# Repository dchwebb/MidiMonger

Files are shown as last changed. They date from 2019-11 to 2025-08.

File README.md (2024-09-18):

<p align="center"><a href="https://www.pcbway.com"> PCBWay</a></p>

# MidiMonger v2
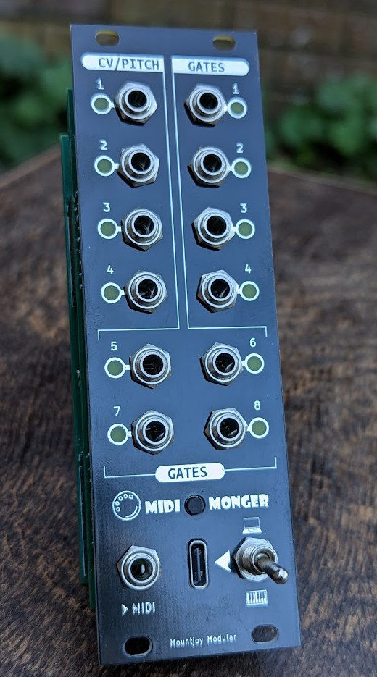
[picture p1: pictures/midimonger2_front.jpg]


MidiMonger is a Eurorack MIDI interface supporting USB and serial MIDI. 

MIDI Monger is a configurable MIDI interface for controlling Eurorack modules from either USB MIDI or Serial MIDI (or both simultaneously). MidiMonger 2 adds support for USB host functionality allowing the use of USB MIDI controllers (and experimentally USB HID mice) to control Eurorack modules.

MIDI Monger has 12 outputs of which 8 are gate outputs and 4 are control voltage outputs. The first eight outputs are configured by default as channel pairs. When assigned a MIDI channel they will act as a monophonic gate/cv driven from a single MIDI channel or in polyphonic mode supporting up to 4 note polyphony.

When not used in a pair a gate output can send a gate for any MIDI note from a channel, for a specific note number on a channel (eg for use as drum triggers) or a clock. The Control Voltage outputs can be configured to send controller data, pitch bend or aftertouch.

Configuration is carried out from a [web interface](https://htmlpreview.github.io/?https://github.com/dchwebb/MidiMonger/blob/master/WebEditor/index.html) using the Chrome browser or via a Virtual COM Port:

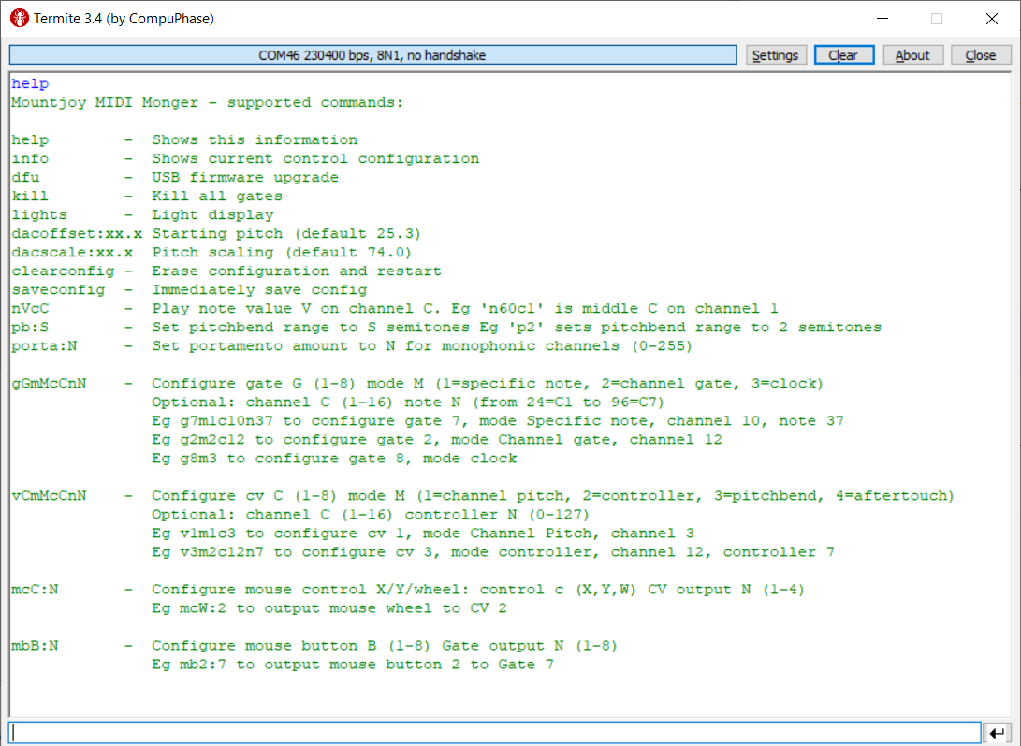
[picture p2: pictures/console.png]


# USB
MidiMonger can act as either a USB device (typically for connection to a computer) or a USB Host (allowing USB Midi controllers to be connected). The mode is selected using a switch on the front panel and is connected with a USB-C socket.

In USB device mode USB MIDI data is merged with MIDI Serial data and sent to the CV and gate outputs as configured. In host mode USB devices can be connected directly to the module. This is typically used for MIDI keyboards and controllers that output via USB, but experimental support is also provided for USB HID devices - mouse support is currently implemented, but joysticks etc could be implemented in the future.

When connecting a USB mouse by default the left/right up/down and mouse wheel are output on CV 1, 2 and 3 and the buttons are output to the gates. This can be configured using the serial console.

In host mode the device will output 5v to power connected devices, but it is not recommended use with power hungry devices as the 5v rail is supplied via a linear regulator which has limited power output and also is used to supply a reference voltage to the DAC.

# Technical
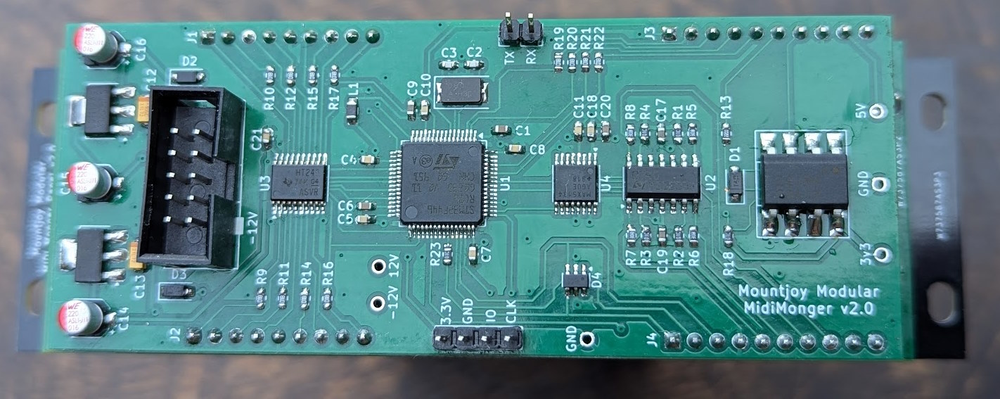
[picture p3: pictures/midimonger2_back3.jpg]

MIDI Monger is controlled by an ARM STM32F446 Microcontroller. The MCU manages USB (device and host modes) and serial MIDI. Control voltages are output from a Maxim MAX5134 16 bit DAC controlled by SPI.

Gate outputs are converted to Eurorack standard of 5V using a SN74HCT244 Octal buffer as a level shifter. MIDI Serial signals are buffered through a 6N137 Optocoupler.

A UART connection is also provided to the module allowing access to the serial console when operating in USB host mode.

Serial MIDI is supplied via a 1/8" TRS jack using the MIDI standard wiring.

Digital power is supplied from a 3.3v linear regulator. An additional 5v regulator is used to supply a reference voltage to the DAC, as power for the octal buffer and also to provide power to USB devices when operating in USB Host mode.

The module is constructed using three PCBs: a component board, a control board and a panel. Schematics and PCB layout created in KiCad v8 and available in [Hardware folder](https://github.com/dchwebb/MidiMonger/tree/master/Hardware_v2).

[Components schematic](Hardware_v2/MidiMonger_Components.pdf)

[Controls schematic](Hardware_v2/MidiMonger_Controls.pdf)

# Errata (v2 hardware)
- The 3.3v linear regulator runs quite warm - some passive PCB cooling would be a good idea or possibly the use of a switched mode power supply (no analog voltages are supplied from this rail).
- A separate switched mode 5V rail would allow the connection of more power hungry USB devices without risking noise or sagging on the analog 5V reference.
- The USB device/host icons on the mode switch front panel should be swapped.
- To allow PWM brightmess control over the CV LEDs, CV1_LED and CV2_LED should be switched to pins lined to TIM4 (CV3_LED and CV4_LED connected to TIM4_CH2 and CH3)

# Version 1 Hardware
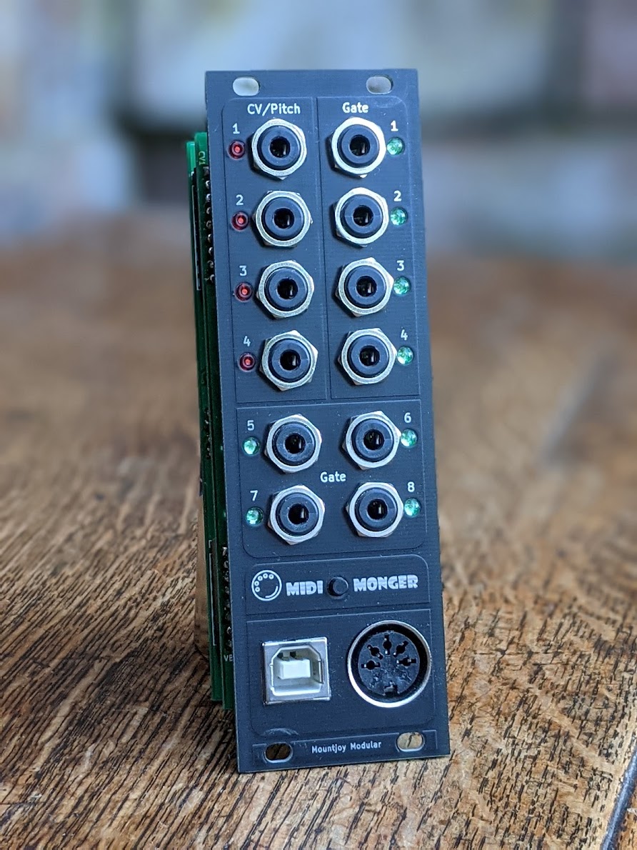
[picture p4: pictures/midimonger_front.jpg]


The original version of the module works with the latest firmware using the build in [V1 Hardware folder](https://github.com/dchwebb/MidiMonger/tree/master/MidiMonger2/v1Hardware). The main differences are that the v1 hardware does not support USB host mode, uses a full size MIDI DIN connector and a USB B socket.

Sponsorship
-----------

[PCBWay](https://www.pcbway.com/) were kind enough to sponsor the v2 module, manufacturing and supplying the three PCBs used for the component and control boards as well as the front panel. The quality of each PCB was excellent and the fine details were crisp and precise. Hand-soldering the fine-pitch components on the prototypes was extremely easy thanks to the high quality accuracy of the solder mask.

Many thanks to PCBWay for their generosity in sponsoring this project and their services come highly recommended.

<p align="center"><a href="https://www.pcbway.com"> PCBWay</a></p>

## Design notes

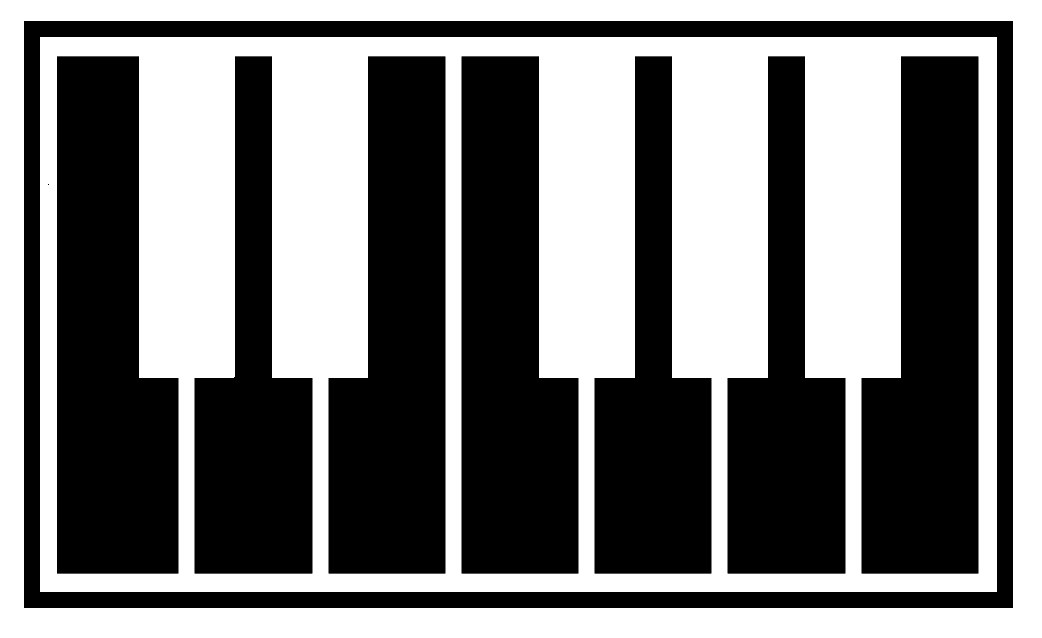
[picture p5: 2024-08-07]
Hardware_v2/Graphics/piano.jpg

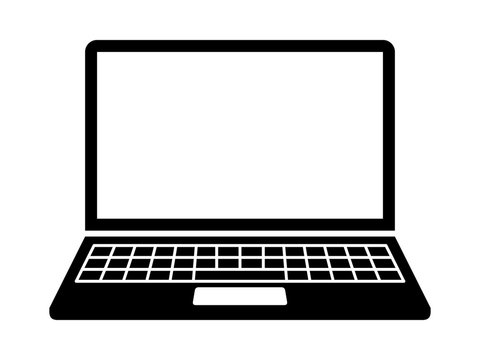
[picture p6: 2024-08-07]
Hardware_v2/Graphics/computer.jpg

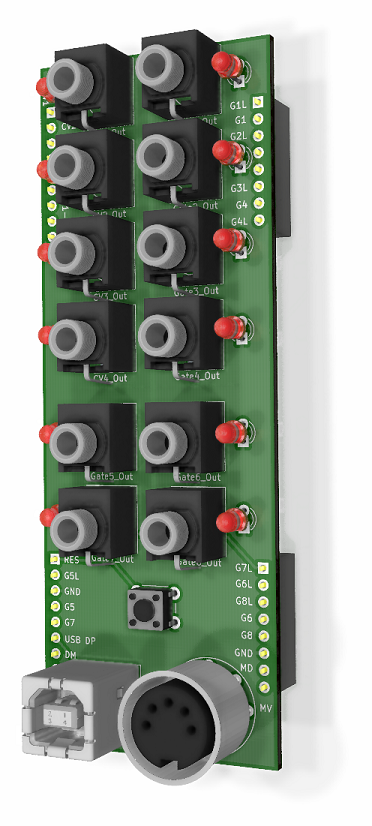
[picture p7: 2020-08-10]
pictures/controls.png

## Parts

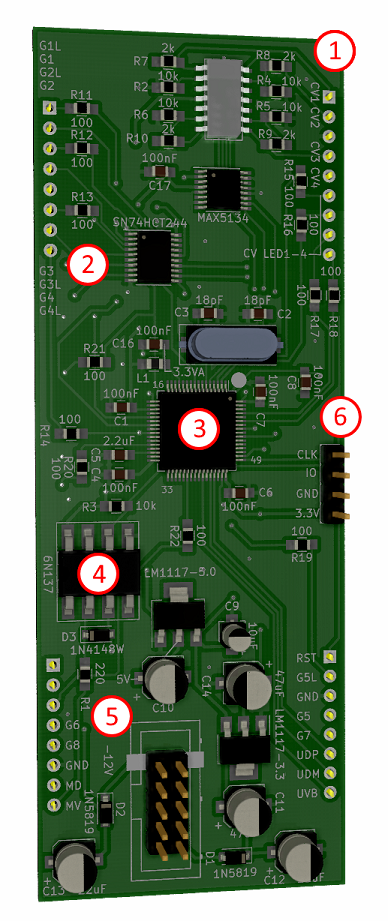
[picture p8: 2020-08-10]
pictures/components.png

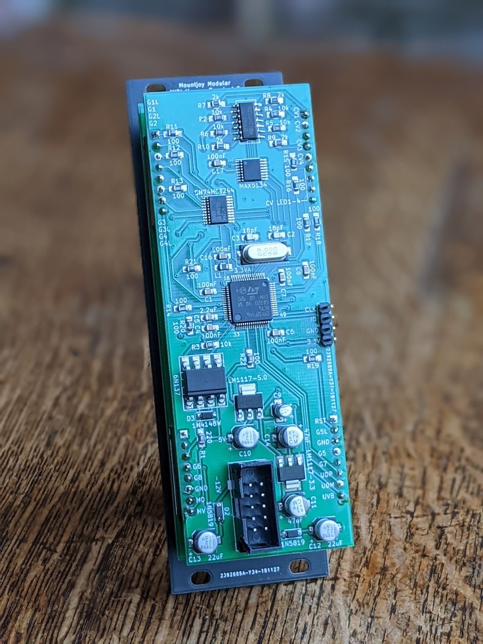
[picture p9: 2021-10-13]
pictures/midimonger_components.jpg

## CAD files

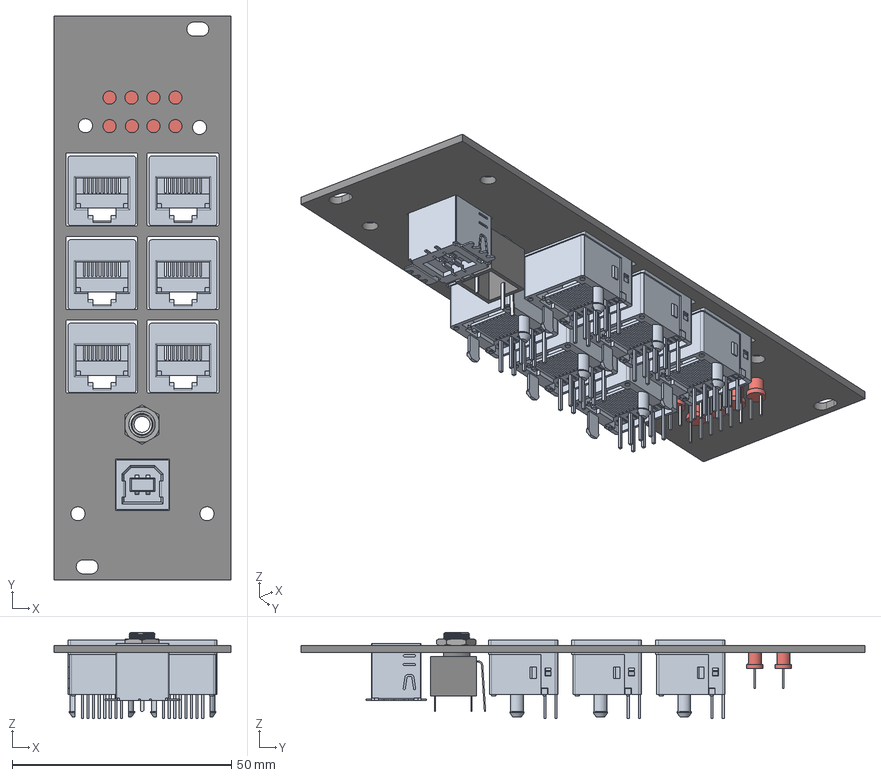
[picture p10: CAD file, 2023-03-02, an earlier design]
Hardware_v1/Graphics/QMidiMonger_panel.step
40.3 x 128.5 x 19.7 mm
QMidiMonger_panel PCB

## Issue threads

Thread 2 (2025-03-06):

enumeration

bgapackage, 2025-03-06:
this does not enumerate in device mode on macosx, not sure why

dchwebb, 2025-03-07:
I haven't actually tested it on macosx as I only have access to a Windows PC here. However it _should_ work.

The module has two modes - it can operate as a device (for connecting it to a computer) or as a host (for connecting to a midi keyboard or mouse). This is controlled by the switch at the bottom right. I think the graphic is unclear and should really be reversed, but up is host mode and down is device mode.

So make sure the switch is in the down position and connect to a computer.

If that doesn't work then it would be worth testing the usb connection by using it in host mode. To do this move the switch to the up position and connect a usb mouse. If you move the mouse or click the buttons the leds should show some activity.

If neither of these work I would guess there is a problem with the soldering, probably around the usb socket.

dchwebb, 2025-03-07:
I'm not sure about the enumeration issue as I don't have a Mac to test on. Any chance you can try it on a Windows machine to see if that works?

Regarding the gate staying high - I have implemented a provisional fix which can be found here:

https://github.com/dchwebb/MidiMonger/tree/master/MidiMonger2/v2Hardware

bgapackage, 2025-03-07:
thanks, ill give that a try.
if it enumerates on windows but not on osx, what do you think it could be? the descriptor?

dchwebb, 2025-03-07:
I really don't know. I can try and test it on Linux which I think has a similar USB engine to MacOS.

Obviously if you could find any troubleshooting tool to provide more info that would be really useful.

dchwebb, 2025-03-08:
I've just tested on Linux and I am seeing descriptor errors and it fails to enumerate. By comparison I have looked at another module of mine which enumerates fine.

This gives me some confidence that I have a replicable issue that I can solve that hopefully will help on a Mac.

bgapackage, 2025-03-08:
amazing, im also trying to debug. keep me posted.

dchwebb, 2025-03-08:
I've done a bit more testing between the module that works and MidiMonger. MidiMonger still fails when I make the descriptors exactly the same as the working module. This implies that the issue is in the way the firmware handles enumeration, rather than a fault in the descriptors themselves.

I'm setting up a debug environment now and hopefully can get to the bottom of it.

dchwebb, 2025-03-09:
I've found and corrected the issue that was preventing the device from being recognised under Linux - it is possible this will fix the issue you have seen on the Mac:

https://github.com/dchwebb/MidiMonger/tree/master/MidiMonger2/v2Hardware

I have noticed one other problem under Linux which is that the serial console is not appearing correctly, though seems to enumerate. If this does now enumerate on your Mac would be you be able to see if you can access the serial terminal?

bgapackage, 2025-03-09:
yep that enumerates and can access serial too. much appreciated

bgapackage, 2025-03-09:
thank you

Closed 2025-03-09.

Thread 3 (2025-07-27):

MidiMonger Roli Seaboard Midihost

tsanderakis, 2025-07-27:
Did this morning some tests to get it running without success.
Direct chain Seaboard going into MidiMonger I can see all CV LEDs going on and off after assigning them from terminal. But there are no cv outs going fe. to Kishoof and s VCF.
When I make the chain Seaboard ->Laptop->MidiOX->Standard Midi Interface->Oscar!->MidiMonger and then to Kishoof / VCF everything is working fine as it should be. Fun to see Midi Data on Oscar. All CV LEDs go on and off and you can hear also the changes  of pitch, on Kishoof, filter or whatever is connected.
Seaboard is connected with an external 12V PSU so I think it will do no harm to the USB connectionr in MidiMonger. No magic smoke and the USB port still working.
Also tried to connect from the web interface and Google Chrome without success. I allowed Chrome to do this but two interfaces not working.
One is a Steinberg and the other a cheap chinese.

tsanderakis, 2025-07-27:
Sorry, no scope here in the moment.
But in this chain including Laptop as Midihost also Gate 1 is working and I use it for opening the VCA in Kishoof.
But as far as I try it in direct connection with Seaboard and MidiMonger Gate 1 no LED.
CV 2, 3, 4, seem to work, as when I connect CV2, CV3, CV4 to the pitch in of Kishoof I can hear the pitch a little bit changing. Ok, this depends on the Midicontrol No.s
In the Laptop chain I can also send cv to a VCF behind Kishoof, so everything fine.
In the direct chain, Seaboard -> MidiMonger CV1 led goes on, but no CV or change and no gate outat No. 1.

And nothing changed with terminal in the setup. Just  changing cables.

tsanderakis, 2025-07-27:
Looks like the translation from Midi In of MidiMonger looks ok, but from Host / USB input not.

dchwebb, 2025-07-27:
Have you set the Device/Host switch to the correct position?

tsanderakis, 2025-07-27:
to the top.
To the bottom nothing to see. No LEDs

dchwebb, 2025-07-27:
Switch up is correct.

I don't suppose you have a UART to serial device? There is a UART console in the module that is useful for troubleshooting USB host MIDI as you don't have access to the normal console in this mode. I use the FTDI friend: https://www.adafruit.com/product/284?srsltid=AfmBOoqUQp6svEJ_5urM25LUVzh_FfFFfu_P-VOsosdgvDhkcROMc2NS

In any case I am assuming that the configuration is not correct. If you go back to device mode and connect to your computer can you use the 'info' command in the console to view your existing configuration?

You will need to know what channel the Seaboard is transmitting on and match your config to that channel. By default the first pair of gate and cvs are connected to MIDI channel 1, the second to channel 2 etc.

tsanderakis, 2025-07-27:
dfu         -  USB firmware upgrade
kill        -  Kill all gates
lights      -  Light display
dacoffset:xx.x Starting pitch (default 25.3)
dacscale:xx.x  Pitch scaling (default 74.0)
clearconfig -  Erase configuration and restart
saveconfig  -  Immediately save config
nVcC        -  Play note value V on channel C. Eg 'n60c1' is middle C on channel 1
pb:S        -  Set pitchbend range to S semitones Eg 'p2' sets pitchbend range to 2 semitones
porta:N     -  Set portamento amount to N for monophonic channels (0-255)

gGmMcCnN    -  Configure gate G (1-8) mode M (1=specific note, 2=channel gate, 3=clock)
               Optional: channel C (1-16) note N (from 24=C1 to 96=C7)
               Eg g7m1c10n37 to configure gate 7, mode Specific note, channel 10, note 37
               Eg g2m2c12 to configure gate 2, mode Channel gate, channel 12
               Eg g8m3 to configure gate 8, mode clock

vCmMcCnN    -  Configure cv C (1-8) mode M (1=channel pitch, 2=controller, 3=pitchbend, 4=aftertouch)
               Optional: channel C (1-16) controller N (0-127)
               Eg v1m1c3 to configure cv 1, mode Channel Pitch, channel 3
               Eg v3m2c12n7 to configure cv 3, mode controller, channel 12, controller 7

mcC:N       -  Configure mouse control X/Y/wheel: control c (X,Y,W) CV output N (1-4)
               Eg mcW:2 to output mouse wheel to CV 2

mbB:N       -  Configure mouse button B (1-8) Gate output N (1-8)
               Eg mb2:7 to output mouse button 2 to Gate 7
info
Configuration:
DAC offset: 25.299999
DAC scale: 74.000000
Pitchbend range: 12.000000 semitones
Portamento amount: 0
Config sector: 5; address: 0x8020360

Gate 1: Channel Gate. Channel: 1 [Mouse Button: 5]
Gate 2: Channel Gate. Channel: 2 [Mouse Button: 6]
Gate 3: Channel Gate. Channel: 3 [Mouse Button: 7]
Gate 4: Channel Gate. Channel: 4 [Mouse Button: 8]
Gate 5: Specific Note. Channel: 10 Note: 36  [Mouse Button: 1]
Gate 6: Specific Note. Channel: 10 Note: 38  [Mouse Button: 2]
Gate 7: Specific Note. Channel: 10 Note: 42  [Mouse Button: 3]
Gate 8: Specific Note. Channel: 10 Note: 46  [Mouse Button: 4]
CV 1: Channel Pitch. Channel: 1 [Mouse: X]
CV 2: Aftertouch. Channel: 1 [Mouse: Y]
CV 3: Controller: 74. Channel: 1 [Mouse: Wheel]
CV 4: Controller: 113. Channel: 1 [Mouse: ]

Only changed CV 2,3 and 4
Rest is default.

dchwebb, 2025-07-27:
That looks ok assuming Seaboard is outputting on channel 1. Can you examine Seaboard's Midi data to check?

tsanderakis, 2025-07-27:
Everything is channel No. 1, because its in Mono Mode. Normally MPE goes polyphonic over severa chanels.
I can try to check with MidiOX whats it sending.

tsanderakis, 2025-07-27:
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
Sorry, think there is no plain text export in Midi OX.
This is a screen shot

tsanderakis, 2025-07-27:
113 / 114 are not coming from the keyboard. This is an extra 5x5cm pad x y.

dchwebb, 2025-07-27:
I'm out of ideas at the moment. I'll see if I can think of any thing further.

tsanderakis, 2025-07-27:
So lets finish for today. Tomorrow is shopping and later I have to do my taxes for 2024 until end of this month. Nothing is running away here so we have time.

tsanderakis, 2025-08-20:
first test
one easy keyboard my old Midiplus 61.
v1m1c1
Configured: v1m1c1
saveconfig
Config Saved (144 bytes at 0x080203f0)
g1m1c1
saveconfig
Config Saved (144 bytes at 0x08020480)

Just activating CV1 and Gate1

CV1 looks good and Kishoof is playing.
Gate1 not.
LED stays on and does not go off and also Gate of Kishoof stays open.

info
Configuration:
DAC offset: 25.299999
DAC scale: 74.000000
Pitchbend range: 12.000000 semitones
Portamento amount: 0
Config sector: 5; address: 0x8020480

Gate 1: Channel Gate. Channel: 1 [Mouse Button: 5]
Gate 2: Channel Gate. Channel: 2 [Mouse Button: 6]
Gate 3: Channel Gate. Channel: 3 [Mouse Button: 7]
Gate 4: Channel Gate. Channel: 4 [Mouse Button: 8]
Gate 5: Specific Note. Channel: 10 Note: 36  [Mouse Button: 1]
Gate 6: Specific Note. Channel: 10 Note: 38  [Mouse Button: 2]
Gate 7: Specific Note. Channel: 10 Note: 42  [Mouse Button: 3]
Gate 8: Specific Note. Channel: 10 Note: 46  [Mouse Button: 4]
CV 1: Channel Pitch. Channel: 1 [Mouse: X]
CV 2: Aftertouch. Channel: 1 [Mouse: Y]
CV 3: Controller: 74. Channel: 1 [Mouse: Wheel]
CV 4: Controller: 113. Channel: 1 [Mouse: ]

Have I done something wrong when configuring?
Just the simplest way pitch on CV1 and Gate on Gate one

tsanderakis, 2025-08-20:
Here it is not working. The normal Midi In works fine but on Midi Host allways the gate stays on. I tested it also with Midi Channel 2 with same result. Gate stays on and this is the problem. I have now two keyboards connected. Old Midiplus 61 and my Arturia Keystep Pro. Both sending on Channel1 and back fom testing Midi Channel 2 to Channel 1. On both Keyboards I can play, works as a Midi Merger, but with Midihost Gate stayes on and when playing the Arturia everything is fine. Even when Gate is on, one Note from the Arturia switches the Gate off.

tsanderakis, 2025-08-20:
The normal Midi In is fine. Just playing Arpeggio with 210BPM which was fast. Nothing hanging and working perfect with a speed nobody is realy using in practice. Normal Midi In is working for 100%.

dchwebb, 2025-08-20:
I might see if I can add some further debugging. By the way have you tried out this debugging mechanism yet?

> You can view the attempted connection log by connecting a device in host mode, then disconnecting. Without restarting the module, switch to device mode and attach to a computer. You can then use a serial console viewer to display the connection details using the command 'hostlog'.

If that works for you then we can get diagnostics of the MIDI host mode over a normal USB connection.

tsanderakis, 2025-08-20:
No, had just a little bit food and fighting now with missing Arturia Passwords that I can connect the Keystep Pro to its Software. MidiOX is not working for 100% now on my computer. Seaboard is found, but the two other keyboards not and this not a save testing ground, Maybe USB cable to long or something wrong with it?

tsanderakis, 2025-08-20:
hostlog

Starting ...
Switching to device mode
USB Device Connected
USB Device Reset Completed
Device Attached. Speed: FS
Enumeration: Got max packet size: 64
Enumeration: Get full device descriptor
 - PID: 0x35
 - VID: 0xccd
Enumeration: Address 1 assigned
Enumeration: Get configuration descriptor size
Enumeration: Got full configuration descriptor
Enumeration: Manufacturer N/A
Enumeration: Product PHECDA USB/MIDI Device
Enumeration: Serial Number N/A
Enumeration done. Device has 1 configuration(s)
Default configuration set
MIDI Class Init
Switching to Interface 1
Class    : 1h
SubClass : 3h
MIDI class started
MIDI Class Process: Init
MIDI Class DeInit
USB Device disconnected
Switching to device mode

dchwebb, 2025-08-22:
I've created a basic debug mechanism to capture raw MIDI events so I can 'replay' them at my end and hopefully see what's going wrong. The way it works is that the first 200 events are captured and can then be displayed in device mode. So it would be great if you could hook up a keyboard that is not working in host mode and play some notes.

Then disconnect, switch to device mode, and connect to a computer. From the serial command line you now have two commands 'eventlistraw' and 'eventlist'. The first dumps the raw MIDI events onto the screen and the second outputs them in a more formatted way. If you could send me the two versions over then I can analyse the data and replay in my module to see if I can fix the issue.

Thanks!
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
tsanderakis, 2025-08-22:
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
And this is what my Keystep Pro is sending to MidiOX. Think it is on Midi Channel1.
When I connect Keystep Pro to MidiMonger there is no reaction and it seems that when controlling with eventlistraw no data has flown and nothing is in the buffer.

tsanderakis, 2025-08-22:
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

Seaboard in Midi OX
Line3 is Note On

tsanderakis, 2025-08-22:
After experimenting with "active sensing" it seems now that USB output of my Midiplus 61 is dead. No more found by MidiOX and tried it on to different PCs. So I need a brake to look whats going on. Active sensing is not clock. Old Keyboards were doing this to look allways if the partner in the chain is responding. On Midiplus61 I see no chance to switch it off. Active sensing information is also on 5pin Midi Out of Midiplus 61 when connected to MidiOX. This is the only midi out working in the moment. USB is comletly dead. Maybe this active sensing is the problem. To much Data?

http://midi.teragonaudio.com/tech/midispec/sense.htm

tsanderakis, 2025-08-22:
Coming back to Seaboard and what I found last evening:
LED on MidiMonger was going on and off when a key was pressed on Seaboard, but when I switched Kishoof and my little speaker on I could hear just a drone and no change in pitch. Midi-hell???
The normal Midi Input of MidiMonger is for me and for now working 100% until now. Ok, have not checked all CV and Gate outs.
But CV1 and Gate1 perfect and as I told you just for testing with an arpeggio with 210bpm.

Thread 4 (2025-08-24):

Midiplus61 Problems

dchwebb, 2025-08-24:
@tsanderakis

I have updated the debugging mechanism to provide a bit of extra detail about potential problems and to filter out the active sensing and blank data events.

Also you only need to run the 'eventlist' command as this contains the raw data and some extra debugging stuff.

Would you mind trying out the new firmware with the Midiplus61 and supplying the resulting event log, please?

tsanderakis, 2025-08-24:
eventlistraw
0x0001b00b
0x0201b00b
0x52309009
0x00309009

Gate LED stays still on.

tsanderakis, 2025-08-24:
eventlist
CIN cable chn msg  db1 db2 Raw
 11     0   0 0x0b   1   0 0x0001b00b
 11     0   0 0x0b   1   2 0x0201b00b
  9     0   0 0x09  48  82 0x52309009
  9     0   0 0x09  48   0 0x00309009
Filtered events: 1964; Multi data events: 123; Split events: 0

tsanderakis, 2025-08-24:
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
Midi Implementation Chart Midiplus61

dchwebb, 2025-08-24:
Firmware updated. Would you mind trying it out for me, please?

tsanderakis, 2025-08-24:
looks nice

dchwebb, 2025-08-24:
Great. I'll close this issue and open a new one for the Arturia Keystep.

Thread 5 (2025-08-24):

Not working with Arturia Keystep

dchwebb, 2025-08-24:
@tsanderakis

Could you try connecting the Keystep and then running the _hostlog_ command in device mode - that will give me a starting point to see why not being recognised.

tsanderakis, 2025-08-24:
eventlistraw
Raw        CIN cable chn msg  db1 db2
Filtered events: 0; Multi data events: 0; Split events: 0

dchwebb, 2025-08-24:
NO - the _hostlog_ command

tsanderakis, 2025-08-24:
But I think we have no chance with this message No registered class for this device.
Think that these USB Keyboards need special drivers installed and then this is enless work.

I`m out and offline for the next 4h todo some sports.

dchwebb, 2025-08-24:
@tsanderakis
Sorry I realised I had not actually updated the firmware on Github, but that is now done.

I've also reworked the code to potentially get the host mode working with Misc class devices (ie hopefully the Keystep and Venom). Could you give it a go if you have a minute, and send me the descriptor debug output in either case?

tsanderakis, 2025-08-24:
Starting ...
USB Device Connected
USB Device Reset Completed
Device Attached. Speed: FS
Enumeration: Got max packet size: 64
Enumeration: Get full device descriptor
 - PID: 0x218
 - VID: 0x1c75
Enumeration: Address 1 assigned
Enumeration: Get configuration descriptor size
Enumeration: Got full configuration descriptor
Enumeration: Manufacturer Arturia
Enumeration: Product KeyStep Pro
Enumeration: Serial Number 000000000001
Enumeration done. Device has 1 configuration(s)
Default configuration set
No registered class for this device 0xfe
USB Device disconnected
Switching to device mode

tsanderakis, 2025-08-25:
After digging deep into all my cabelboxes and other stuff I found my external Midi Host back this morning.
Miditech USB Midi Host
https://miditech.de/en/portfolio/usb-midi-host/

Keystep to Miditech USB Midi Host to MidiMonger
And it`s working!
And this is nothing where you have to install drivers. Just Hardware and found. There must be a way that MidiMonger will find these Keyboards.

But,
test No. 2 this morning, changed over to the old Venom, it`s not working. So there must be something else.
And at the end I just ordered for r&d a cheap USB Midihost for 25€ and then let`s look and see what this little box is doing.
Arriving ~thursday.

tsanderakis, 2025-08-25:
hostlog
USB Device Connected
USB Device Reset Completed
Device Attached. Speed: FS
Enumeration: Got max packet size: 64
Enumeration: Get full device descriptor
 - PID: 0x218
 - VID: 0x1c75
Enumeration: Address 1 assigned
Enumeration: Get configuration descriptor size
Enumeration: Got full configuration descriptor
Enumeration: Manufacturer Arturia
Enumeration: Product KeyStep Pro
Enumeration: Serial Number 000000000001
Enumeration done. Device has 1 configuration(s)
Default configuration set
No registered class for this device 0xfe
USB Device disconnected
USB Device Connected
USB Device disconnected
Switching to device mode

dchwebb, 2025-08-26:
Thanks - I've had another go at fixing. Could you try again at some point, please?

tsanderakis, 2025-08-26:
Looks good now and working. Have my CV and my Gate and Kishoof is playing.

hostlog

Starting ...
USB Device Connected
USB Device Reset Completed
Device Attached. Speed: FS
Enumeration: Got max packet size: 64
Enumeration: Get full device descriptor
 - PID: 0x218
 - VID: 0x1c75
Enumeration: Address 1 assigned
Enumeration: Get configuration descriptor size
Enumeration: Got full configuration descriptor
Enumeration: Manufacturer Arturia
Enumeration: Product KeyStep Pro
Enumeration: Serial Number 000000000001
Enumeration done. Device has 1 configuration(s)
Default configuration set
MIDI Class Init
Switching to Interface 2
Class    : 1h
SubClass : 3h
MIDI class started
MIDI Class Process: Init
MIDI Class DeInit
USB Device disconnected
Switching to device mode

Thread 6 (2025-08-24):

Not working  with Venom

tsanderakis, 2025-08-24:
hostlog

USB Device Connected
USB Device Reset Completed
Device Attached. Speed: FS
Enumeration: Got max packet size: 64
Enumeration: Get full device descriptor
 - PID: 0x2084
 - VID: 0x763
Enumeration: Address 1 assigned
Enumeration: Get configuration descriptor size
Enumeration: Got full configuration descriptor
Enumeration: Manufacturer M-Audio
Enumeration: Product Venom
Enumeration: Serial Number N/A
Enumeration done. Device has 1 configuration(s)
Default configuration set
MIDI Class Init
Error: Cannot Select This Interface
Cannot Find the interface for MIDI class
Device does not support MIDI class
MIDI Class DeInit
USB Device disconnected
Switching to device mode

This is my no.4 and last keyboard with USB und it seems that it is the same problem like Keystep Pro.

Device does not support MIDI class

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

dchwebb, 2025-08-26:
It looks like the problem with the Venom is possibly because the USB descriptor is larger than the current maximum size allowed in MidiMonger. I've increased the maximum size so if you could try again that would be great.

tsanderakis, 2025-08-26:
hostlog

Starting ...
USB Device Connected
USB Device Reset Completed
Device Attached. Speed: FS
Enumeration: Got max packet size: 64
Enumeration: Get full device descriptor
 - PID: 0x2084
 - VID: 0x763
Enumeration: Address 1 assigned
Enumeration: Got configuration descriptor size
Enumeration: Got full configuration descriptor
Enumeration: Manufacturer M-Audio
Enumeration: Product Venom
Enumeration: Serial Number N/A
Enumeration done. Device has 1 configuration(s)
Default configuration set
MIDI Class Init
Error: Cannot Select This Interface
Cannot Find the interface for MIDI class
No registered class for this device 0x01
USB Device disconnected
Switching to device mode

dchwebb, 2025-08-26:
There's something a bit funny about that descriptor - it could be that I'm not parsing it correctly or it could have an odd format.

If you are happy to keep on going with the debugging I'll write some additional tools to help find out where this is failing.

dchwebb, 2025-08-26:
OK - if you update to the latest firmware there is a new command 'rawconfigdesc' which will output the raw configuration descriptor data so I can see why the parsing is not working correctly.

tsanderakis, 2025-08-26:
So just in between before going on, there is maybe one more problem with the firmware. I was feeding MidiMonger from Keystep Pro with a sequence ~120BPM, having a beer, enjoying this crazy music, and what happend after ~7,8,10min??? MidiMonger is frozen. Short reset and everything is fine again. After the same time- again frozen. So I can reproduce this issue.
Think I will play a little bit more tomorrow to find out if there are more problems.

tsanderakis, 2025-08-26:
rawconfigdesc
Raw configuration descriptor data
0x09 0x02 0x48 0x01 0x05 0x01 0x04 0xc0
0000 0x09 0x04 0000 0000 0000 0x01 0x01
0000 0x03 0x0b 0x24 0x01 0000 0x01 0x49
0000 0x03 0x01 0x02 0x03 0x0c 0x24 0x02
0x01 0x01 0x01 0x02 0x02 0x03 0000 0000
0000 0x09 0x24 0x03 0x02 0x01 0x03 0x01
0x06 0000 0x0c 0x24 0x02 0x03 0x01 0x02
0x04 0x02 0x03 0000 0000 0000 0x09 0x24
0x03 0x04 0x01 0x01 0x03 0x05 0000 0x0a
0x24 0x06 0x05 0x03 0x01 0x01 0000 0000
0000 0x0a 0x24 0x06 0x06 0x01 0x01 0x01
0x02 0x02 0000 0x09 0x04 0x01 0000 0000
0x01 0x02 0000 0000 0x09 0x04 0x01 0x01
0x02 0x01 0x02 0000 0000 0x07 0x24 0x01
0x01 0x02 0x01 0000 0x0b 0x24 0x02 0x01
0x02 0x03 0x18 0x01 0x44 0xac 0000 0x09
0x05 0x02 0x05 0x3e 0x01 0x01 0000 0x86
0x07 0x25 0x01 0x01 0000 0000 0000 0x09
0x05 0x86 0x01 0x10 0000 0x01 0x06 0000
0x09 0x04 0x02 0000 0000 0x01 0x02 0000
0000 0x09 0x04 0x02 0x01 0x01 0x01 0x02
0000 0000 0x07 0x24 0x01 0x04 0x01 0x01
0000 0x0b 0x24 0x02 0x01 0x02 0x03 0x18
0x01 0x44 0xac 0000 0x09 0x05 0x84 0x05
0x3e 0x01 0x01 0000 0000 0x07 0x25 0x01
0x01 0000 0000 0000 0x09 0x04 0x03 0000
0x02 0x01 0x03 0000 0x03 0x07 0x24 0x01
0000 0x01 0x61 0000 0x06 0x24 0x02 0x01
0x01 0x05 0x06 0x24 0x02 0x01 0x02 0x06
0x06 0x24 0x02 0x02 0x03 0x07 0x06 0x24
0x02 0x02 0x04 0x08 0x09 0x24 0x03 0x01
0x05 0x01 0x03 0x01 0x07 0x09 0x24 0x03
0x01 0x06 0x01 0x04 0x02 0x08 0x09 0x24
0x03 0x02 0x07 0x01 0x01 0x01 0x05 0x09
0x24 0x03 0x02 0x08 0x01 0x02 0x02 0x06
0x09 0x05 0x0d 0x02 0x40 0000 0000 0000
0000 0x06 0x25 0x01 0x02 0x01 0x02 0x09
0x05 0x8e 0x02 0x40 0000 0000 0000 0000
0x06 0x25 0x01 0x02 0x05 0x06 0x09 0x04
0x04 0000 0000 0xfe 0x01 0x01 0x09 0x09
0x21 0x01 0xd0 0x07 0x0c 0x20 0x01 0x01
0000 0000 0000 0000 0000 0000 0000 0000
0000 0000 0000 0000 0000 0000 0000 0000
0000 0000 0000 0000 0000 0000 0000 0000
0000 0000 0000 0000 0000 0000 0000 0000
0000 0000 0000 0000 0000 0000 0000 0000
0000 0000 0000 0000 0000 0000 0000 0000
0000 0000 0000 0000 0000 0000 0000 0000
0000 0000 0000 0000 0000 0000 0000 0000
0000 0000 0000 0000 0000 0000 0000 0000
0000 0000 0000 0000 0000 0000 0000 0000
0000 0000 0000 0000 0000 0000 0000 0000
0000 0000 0000 0000 0000 0000 0000 0000
0000 0000 0000 0000 0000 0000 0000 0000
0000 0000 0000 0000 0000 0000 0000 0000
0000 0000 0000 0000 0000 0000 0000 0000
0000 0000 0000 0000 0000 0000 0000 0000
0000 0000 0000 0000 0000 0000 0000 0000
0000 0000 0000 0000 0000 0000 0000 0000
0000 0000 0000 0000 0000 0000 0000 0000
0000 0000 0000 0000 0000 0000 0000 0000
0000 0000 0000 0000 0000 0000 0000 0000
0000 0000 0000 0000 0000 0000 0000 0000
0000 0000 0000 0000 0000 0000 0000 0000

lots of zero at the end buffer big enough?

dchwebb, 2025-08-27:
I think the latest firmware should resolve the issue with Venom - could you test and send me the results of the _descriptor_ and _hostlog_ commands, please?

Once we've got that sorted I'll move onto the hanging issue.

tsanderakis, 2025-08-27:
hostlog

Starting ...
USB Device Connected
USB Device Reset Completed
Device Attached. Speed: FS
Enumeration: Got max packet size: 64
Enumeration: Get full device descriptor
 - PID: 0x2084
 - VID: 0x763
Enumeration: Address 1 assigned
Enumeration: Got configuration descriptor size
Enumeration: Got full configuration descriptor
Enumeration: Manufacturer M-Audio
Enumeration: Product Venom
Enumeration: Serial Number N/A
Enumeration done. Device has 1 configuration(s)
Default configuration set
MIDI Class Init
Switching to Interface 5
Class    : 1h
SubClass : 3h
MIDI class started
MIDI Class Process: Init
MIDI Class DeInit
USB Device disconnected
Switching to device mode

tsanderakis, 2025-08-27:
descriptor
Device Descriptor:
bLength: 0x12
bDescriptorType: 0x01
bcdUSB: 0x0101
bDeviceClass: 0000
bDeviceSubClass: 0000
bDeviceProtocol: 0000
bMaxPacketSize: 0x40
idVendor: 0x0763
idProduct: 0x2084
bcdDevice: 0x1154
iManufacturer: 0x02
iProduct: 0x03
iSerialNumber: 0000
bNumConfigurations: 0x01

Config Descriptor:
bLength: 0x09
bDescriptorType: 0x02
wTotalLength: 0x0148
bNumInterfaces: 0x05
bConfigurationValue: 0x01
iConfiguration: 0x04
bmAttributes: 0xc0
bMaxPower: 0000

Interface Descriptor:
bLength: 0x09
bDescriptorType: 0x04
bInterfaceNumber: 0000
bAlternateSetting: 0000
bNumEndpoints: 0000
bInterfaceClass: 0x01
bInterfaceSubClass: 0x01
bInterfaceProtocol: 0000
iInterface: 0x03

Interface Descriptor:
bLength: 0x09
bDescriptorType: 0x04
bInterfaceNumber: 0x01
bAlternateSetting: 0000
bNumEndpoints: 0000
bInterfaceClass: 0x01
bInterfaceSubClass: 0x02
bInterfaceProtocol: 0000
iInterface: 0000

Interface Descriptor:
bLength: 0x09
bDescriptorType: 0x04
bInterfaceNumber: 0x01
bAlternateSetting: 0x01
bNumEndpoints: 0x02
bInterfaceClass: 0x01
bInterfaceSubClass: 0x02
bInterfaceProtocol: 0000
iInterface: 0000

Endpoint Descriptor:
bLength: 0x09
bDescriptorType: 0x05
bEndpointAddress: 0x02
bmAttributes: 0x05
wMaxPacketSize: 0x013e
bInterval: 0x01

Endpoint Descriptor:
bLength: 0x09
bDescriptorType: 0x05
bEndpointAddress: 0x86
bmAttributes: 0x01
wMaxPacketSize: 0x0010
bInterval: 0x01

Interface Descriptor:
bLength: 0x09
bDescriptorType: 0x04
bInterfaceNumber: 0x02
bAlternateSetting: 0000
bNumEndpoints: 0000
bInterfaceClass: 0x01
bInterfaceSubClass: 0x02
bInterfaceProtocol: 0000
iInterface: 0000

Interface Descriptor:
bLength: 0x09
bDescriptorType: 0x04
bInterfaceNumber: 0x02
bAlternateSetting: 0x01
bNumEndpoints: 0x01
bInterfaceClass: 0x01
bInterfaceSubClass: 0x02
bInterfaceProtocol: 0000
iInterface: 0000

Endpoint Descriptor:
bLength: 0x09
bDescriptorType: 0x05
bEndpointAddress: 0x84
bmAttributes: 0x05
wMaxPacketSize: 0x013e
bInterval: 0x01

Interface Descriptor:
bLength: 0x09
bDescriptorType: 0x04
bInterfaceNumber: 0x03
bAlternateSetting: 0000
bNumEndpoints: 0x02
bInterfaceClass: 0x01
bInterfaceSubClass: 0x03
bInterfaceProtocol: 0000
iInterface: 0x03

Endpoint Descriptor:
bLength: 0x09
bDescriptorType: 0x05
bEndpointAddress: 0x0d
bmAttributes: 0x02
wMaxPacketSize: 0x0040
bInterval: 0000

Endpoint Descriptor:
bLength: 0x09
bDescriptorType: 0x05
bEndpointAddress: 0x8e
bmAttributes: 0x02
wMaxPacketSize: 0x0040
bInterval: 0000

Interface Descriptor:
bLength: 0x09
bDescriptorType: 0x04
bInterfaceNumber: 0x04
bAlternateSetting: 0000
bNumEndpoints: 0000
bInterfaceClass: 0xfe
bInterfaceSubClass: 0x01
bInterfaceProtocol: 0x01
iInterface: 0x09

tsanderakis, 2025-08-27:
Big fun.
My last Beta Test was ~30 years ago for a swedish company called Propellerheads and their Recycle. In these old days I was testing SCSI communication between samplers and Win PCs with SCSI Card.

dchwebb, 2025-08-27:
> Big fun. My last Beta Test was ~30 years ago for a swedish company called Propellerheads and their Recycle. In these old days I was testing SCSI communication between samplers and Win PCs with SCSI Card.

Very cool! You've certainly done a great job helping find and fix all the issues in this project ...

tsanderakis, 2025-08-28:
This afternoon I was a little bit playing around with the web editor.
So up to now it looks good.
First I was a little bit confused with my Firefox but then changed to Chrome and everything was working.

tsanderakis, 2025-08-28:
Keystep Pro working
BopPad working
Midiplus61 working
Seaboard working
Venom working

So everything ok here

dchwebb, 2025-08-29:
That's great news - thanks so much for helping debug and fix all those issues. I'll close this issue, but feel free to open others if there are improvements or fixes to be done.

Closed 2025-08-29.

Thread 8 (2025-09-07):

Pitchbend LED / web editor

tsanderakis, 2025-09-07:
Was a little bit playing around with the web editor. Is it normal, that when pressing Test, at CV4 and Pitchbend the LED is **not** going on? When sending fe. a controller everything is fine with LED and CV4.
Or maybe I`m wrong?
Keep cool and do whatever you have to do in the moment. So this is something when you have a little bit more time.

tsanderakis, 2025-09-27:
welcome back
Sorry, will check this later in the afternoon. Going with my brother to a model train fleamarket and be back in ~4h.

tsanderakis, 2025-09-27:
Testing now since 1.5h.

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
Looks nearly good now. Seaboard is connected to USB MidiMonger -> Kishoof -> 2 channel input VCF -> speaker.
Have now on all CV outputs my CVs and they are doing something. So I have to learn a little bit more about the best chain amd routing.
CV 1 going to1v/oct, CV3 to wavetable input 2 on Kishoof and CV2 and CV 4 going to VCF. Gate 1 to VCA of Kishoof. Seems that everything is working fine.
But then I came across this problem, that after an uncertain time I`m loosing my octaves means tuning. One octave is then not 12. Its a little bit more and out of tune.
Startet a vsti on my laptop, connecting Seaboard and everything is fine and tune ok. Going back inserting cable into MidiMonger everything fine without doing a reset just plug and play, but again after uncertain time same problem with tuning.
Question now is who ist the bad boy in this game and I have to find out a little bit more information about the problem. Will later connect a differen Keyboard to MidiMonger and try to reproduce this tuning error again.

tsanderakis, 2025-09-27:
And webeditor is working.

dchwebb, 2025-09-28:
One possbile cause of tuning changing is if there are problems with the 5v line as this provides the analogue voltage reference to the DAC. If a MIDI device is connected that is drawing too much current from the 5v line this could possibly cause the issue.

tsanderakis, 2025-09-28:
Ok, I will try later in the evening with a PSU and make also No.2 ready with new firmware and try with this one if I can reprroduce the problem.

tsanderakis, 2025-09-29:
Yesterday evening the Seaboard + chain + external PSU was running for about 6h without any problem. Looks good.
First I was thinking that this rechargeable battery is buffering but think that only the charging of it is to much for the 5V line.
Better using keyboards with PSU.
Think we can close.

dchwebb, 2025-09-29:
Precision DACs are pretty expensive, but there is one ST microcontroller that has 7 12 bit DACs built in - I have used it on a couple of projects. That could be a good option for general CV outputs whilst using a smaller (and cheaper) precision DAC for the v/oct outputs.

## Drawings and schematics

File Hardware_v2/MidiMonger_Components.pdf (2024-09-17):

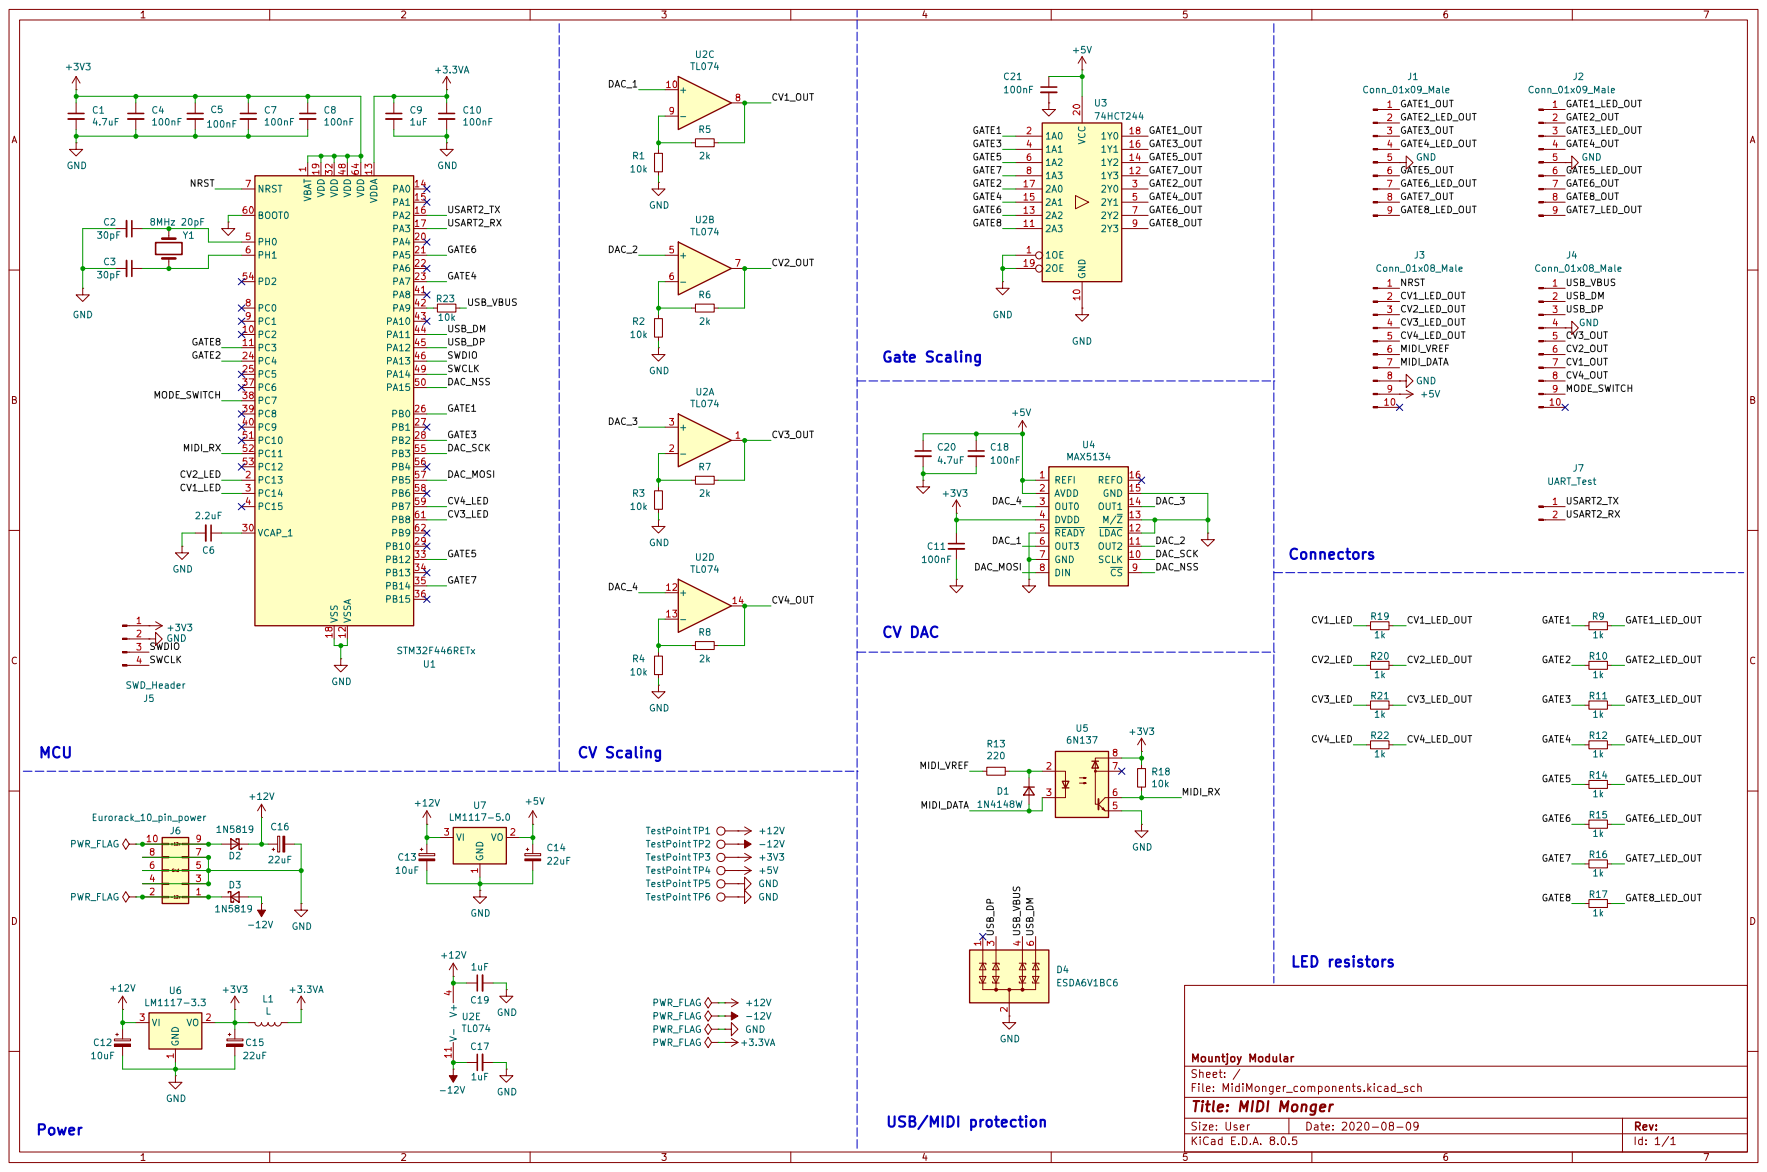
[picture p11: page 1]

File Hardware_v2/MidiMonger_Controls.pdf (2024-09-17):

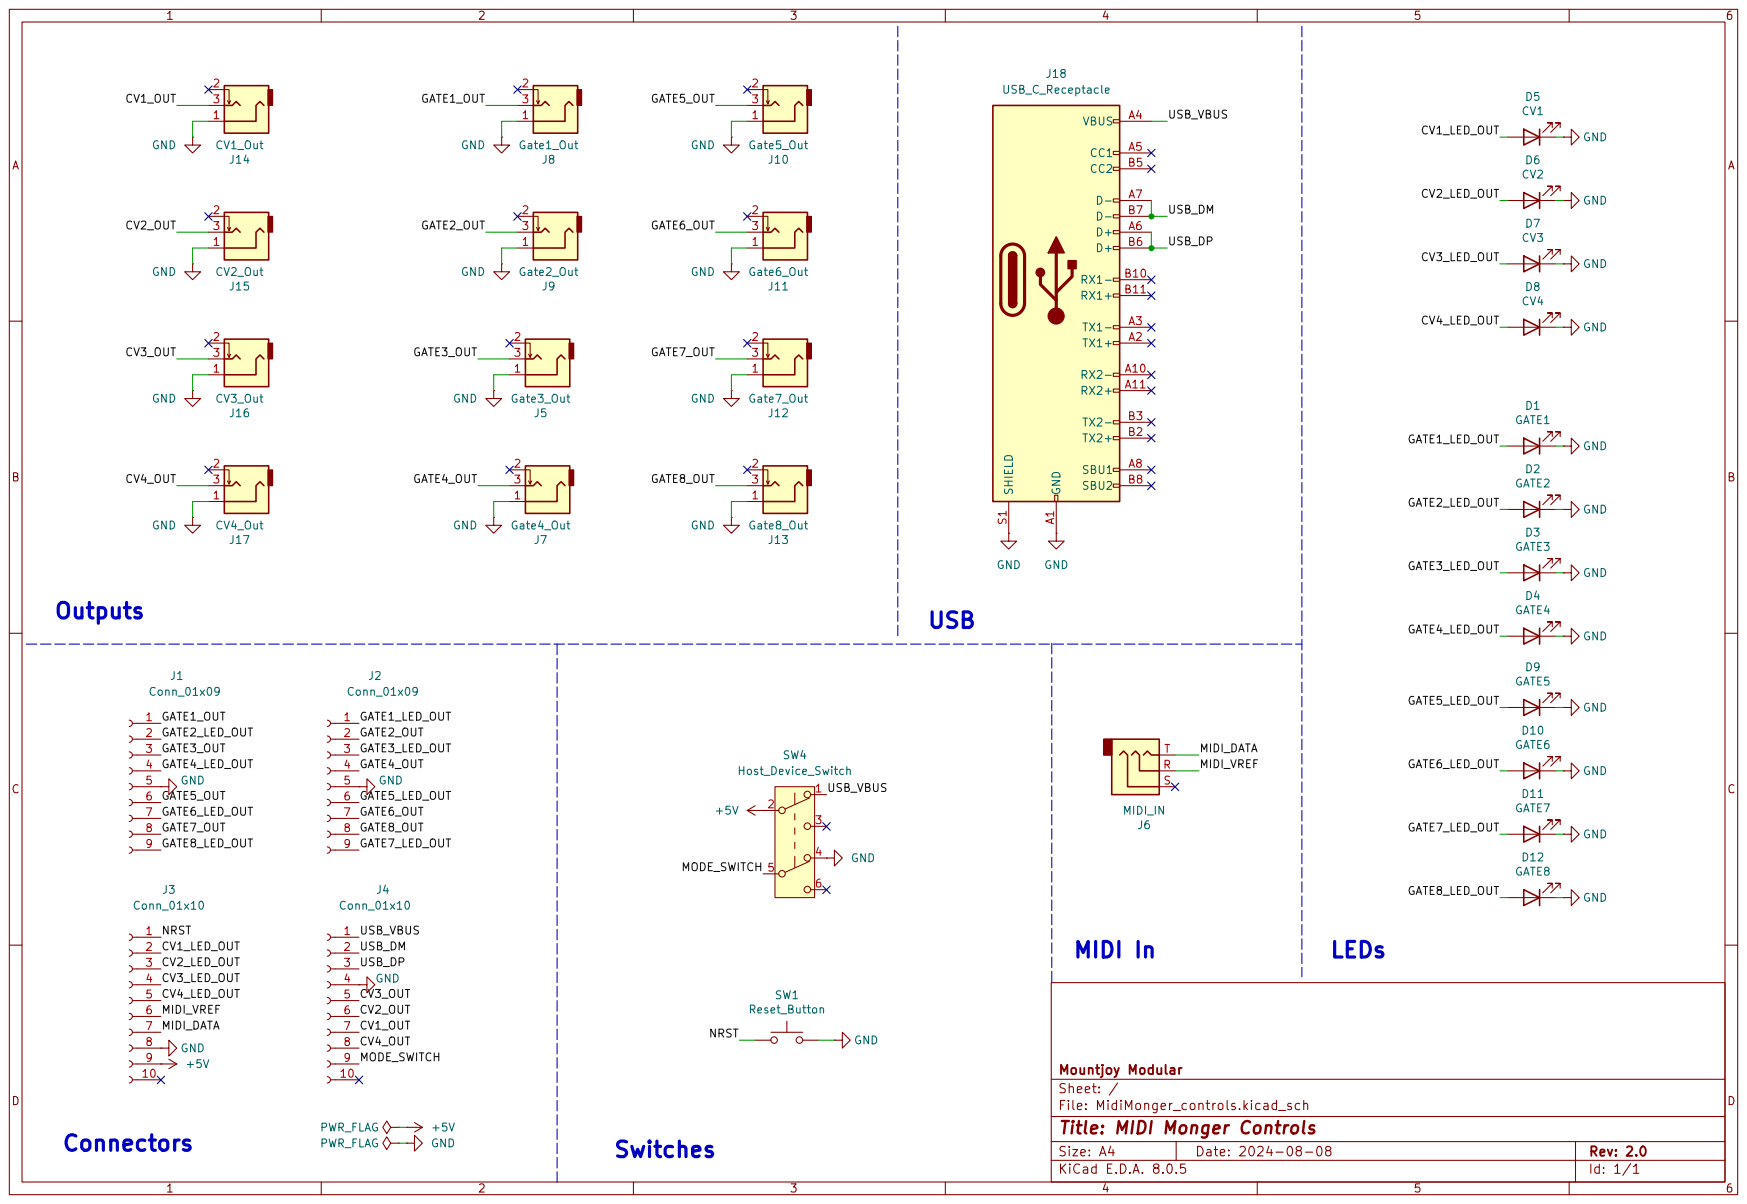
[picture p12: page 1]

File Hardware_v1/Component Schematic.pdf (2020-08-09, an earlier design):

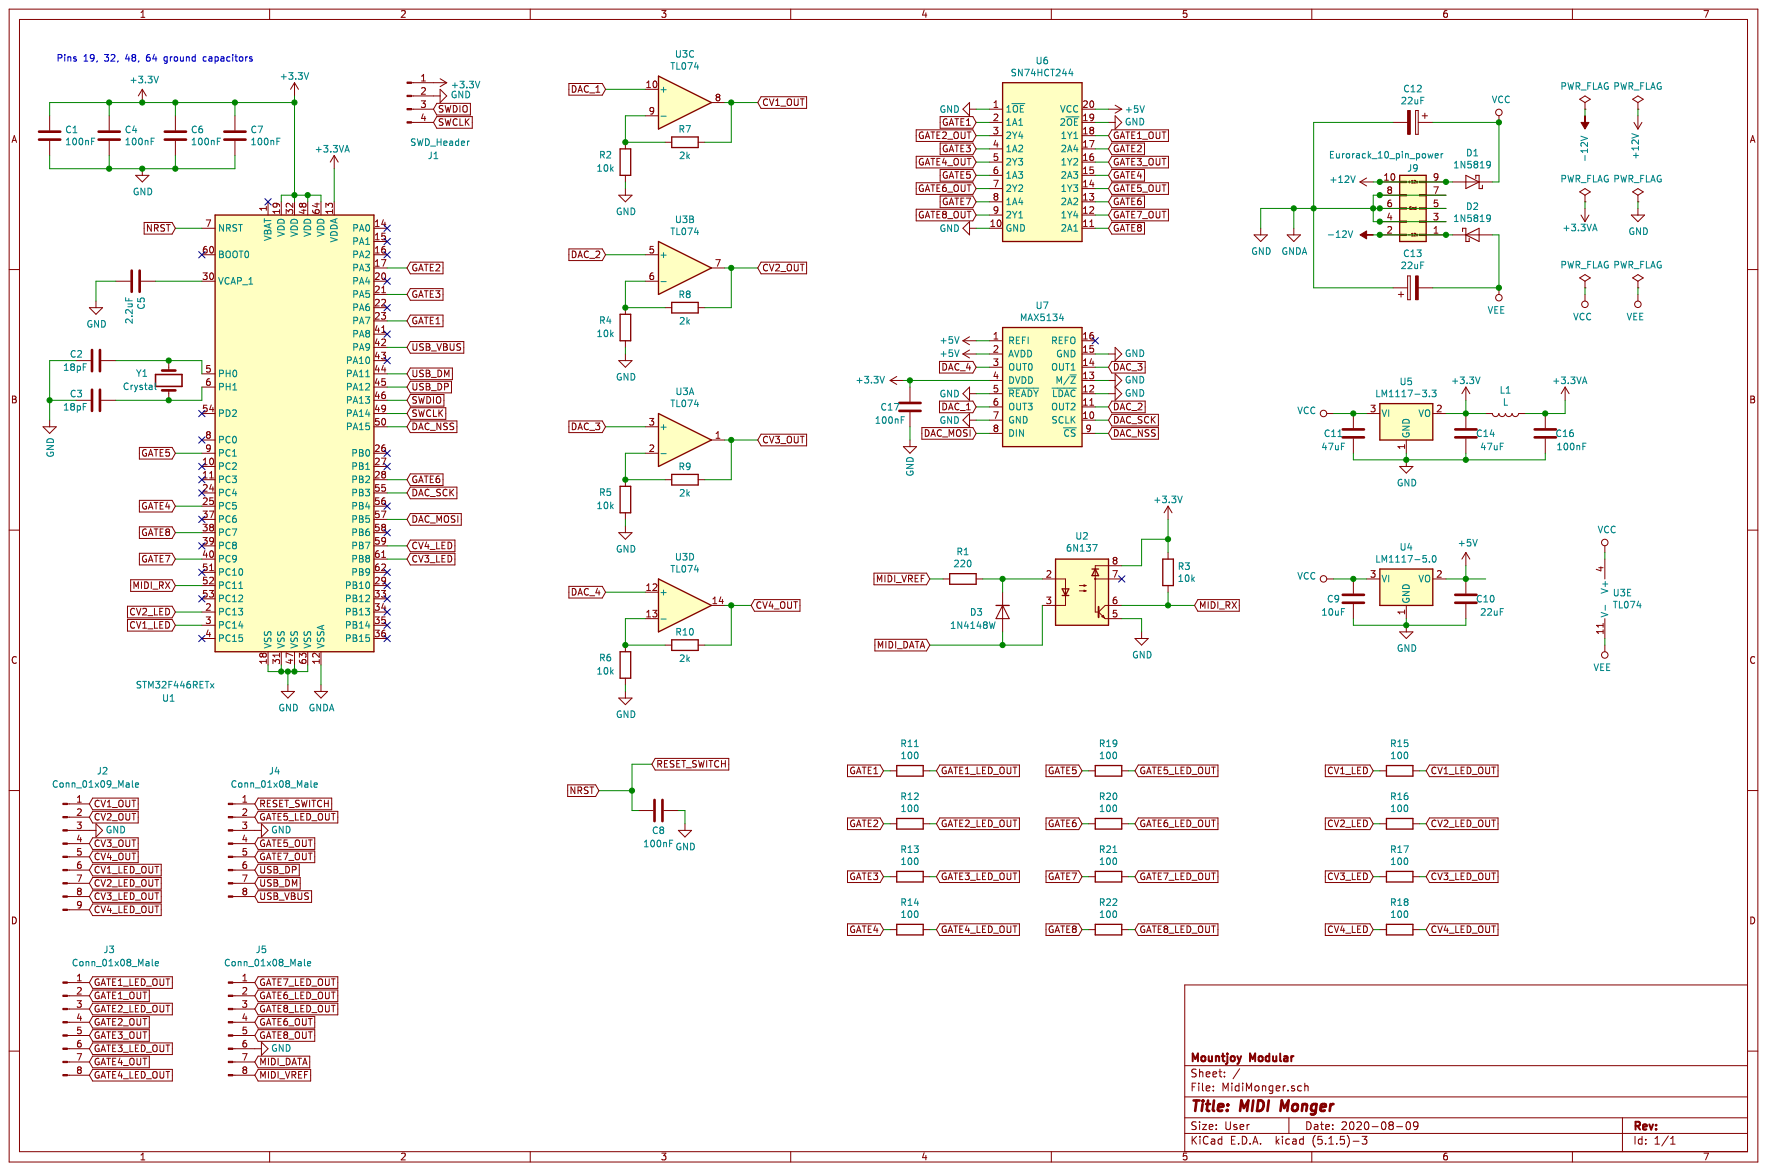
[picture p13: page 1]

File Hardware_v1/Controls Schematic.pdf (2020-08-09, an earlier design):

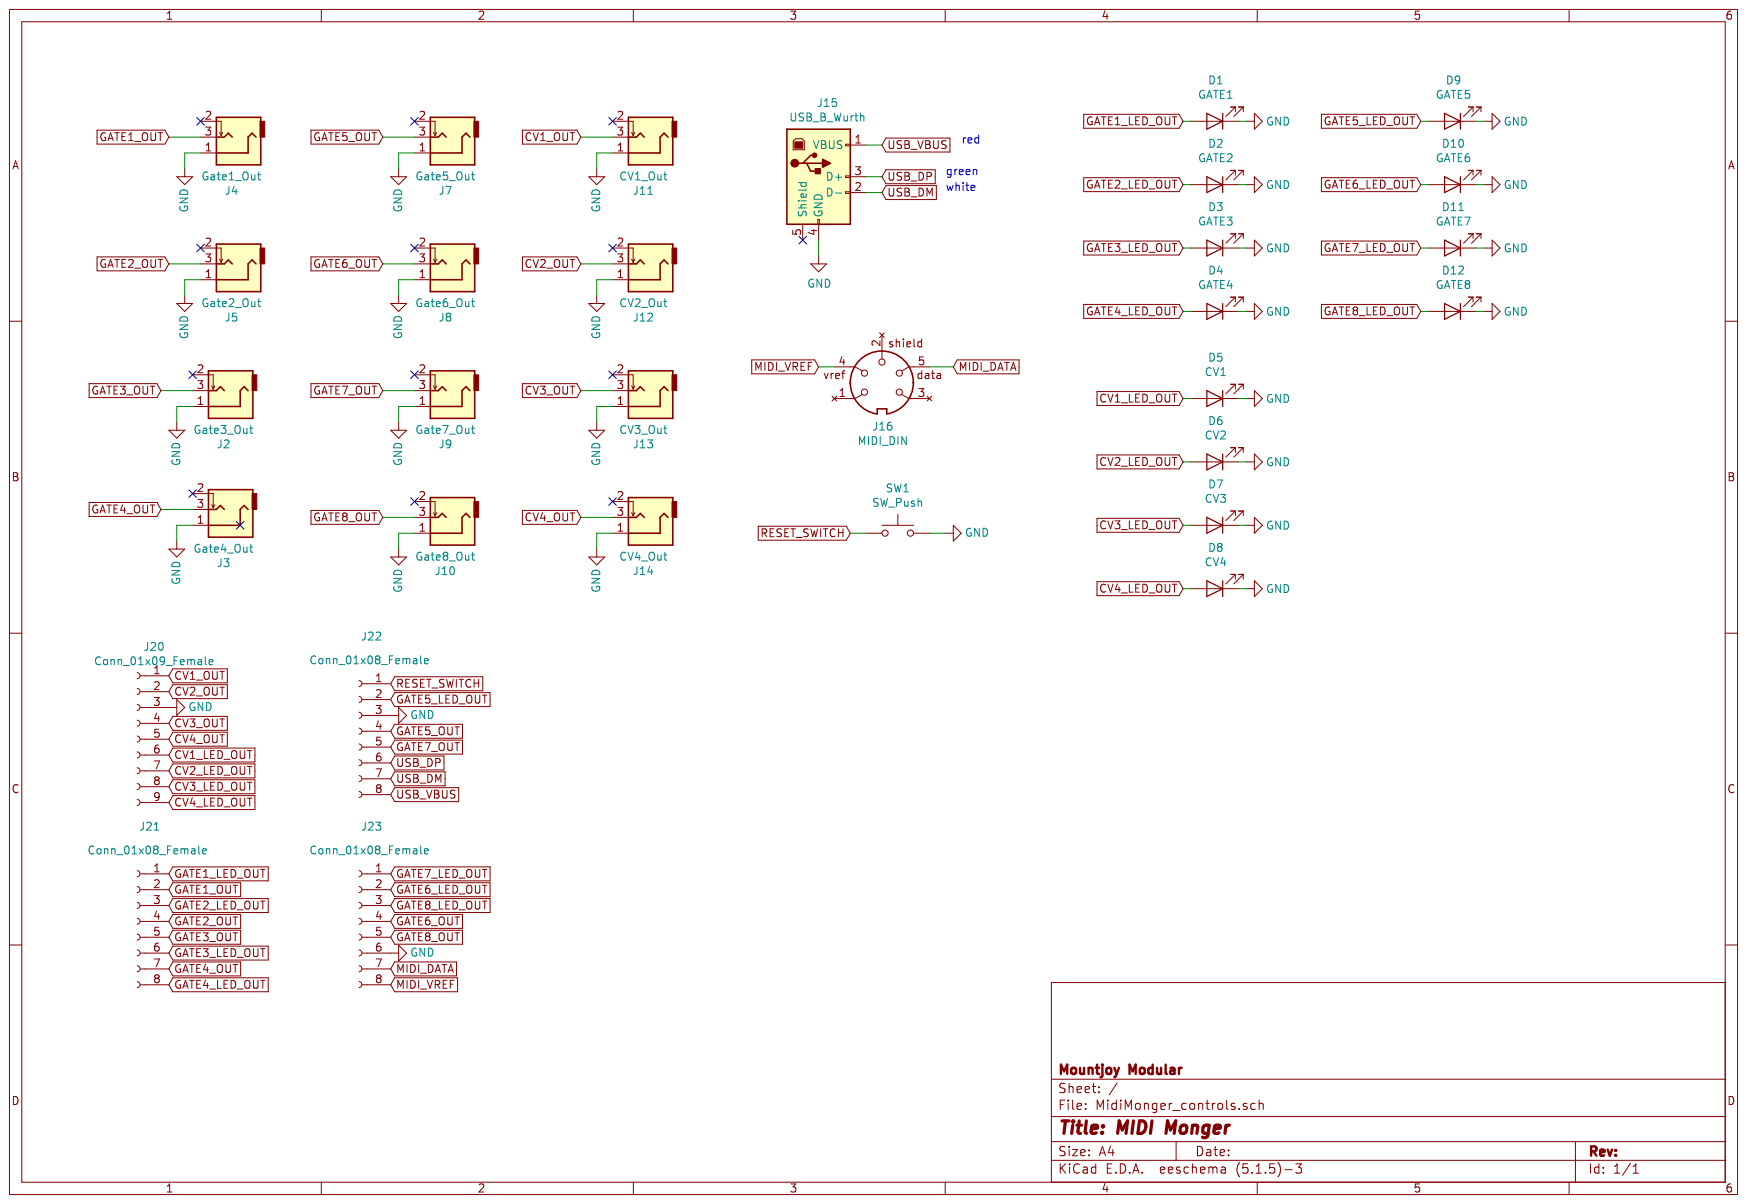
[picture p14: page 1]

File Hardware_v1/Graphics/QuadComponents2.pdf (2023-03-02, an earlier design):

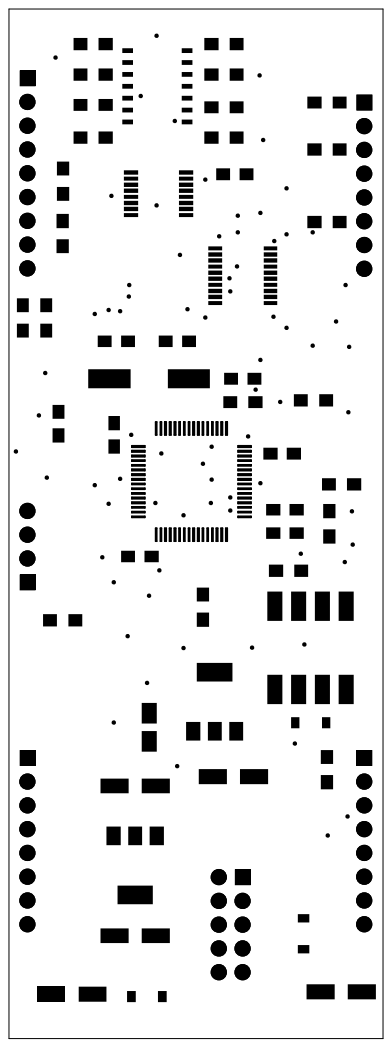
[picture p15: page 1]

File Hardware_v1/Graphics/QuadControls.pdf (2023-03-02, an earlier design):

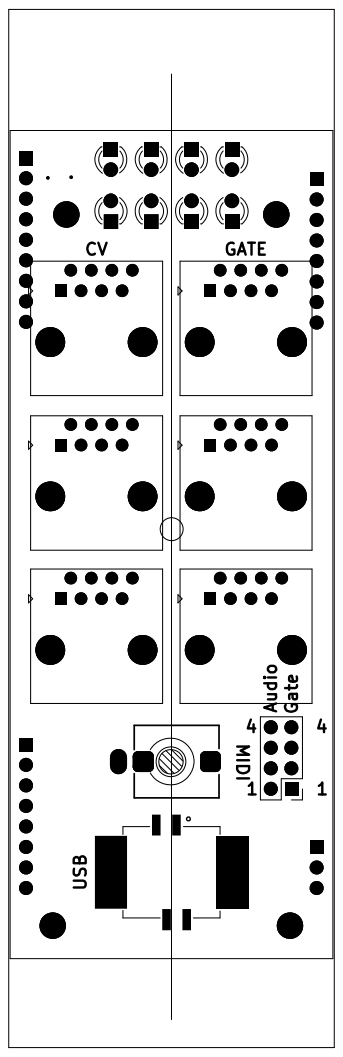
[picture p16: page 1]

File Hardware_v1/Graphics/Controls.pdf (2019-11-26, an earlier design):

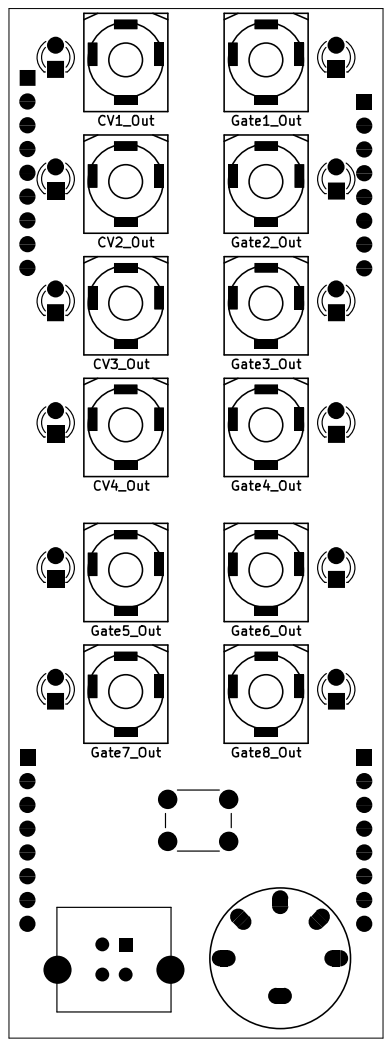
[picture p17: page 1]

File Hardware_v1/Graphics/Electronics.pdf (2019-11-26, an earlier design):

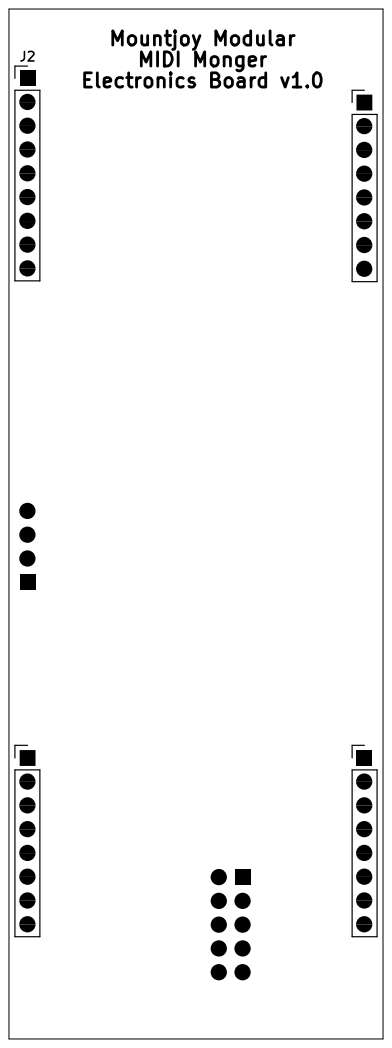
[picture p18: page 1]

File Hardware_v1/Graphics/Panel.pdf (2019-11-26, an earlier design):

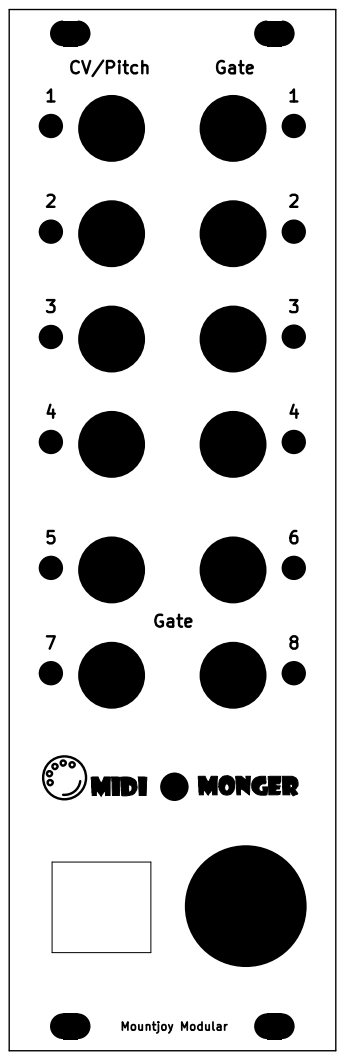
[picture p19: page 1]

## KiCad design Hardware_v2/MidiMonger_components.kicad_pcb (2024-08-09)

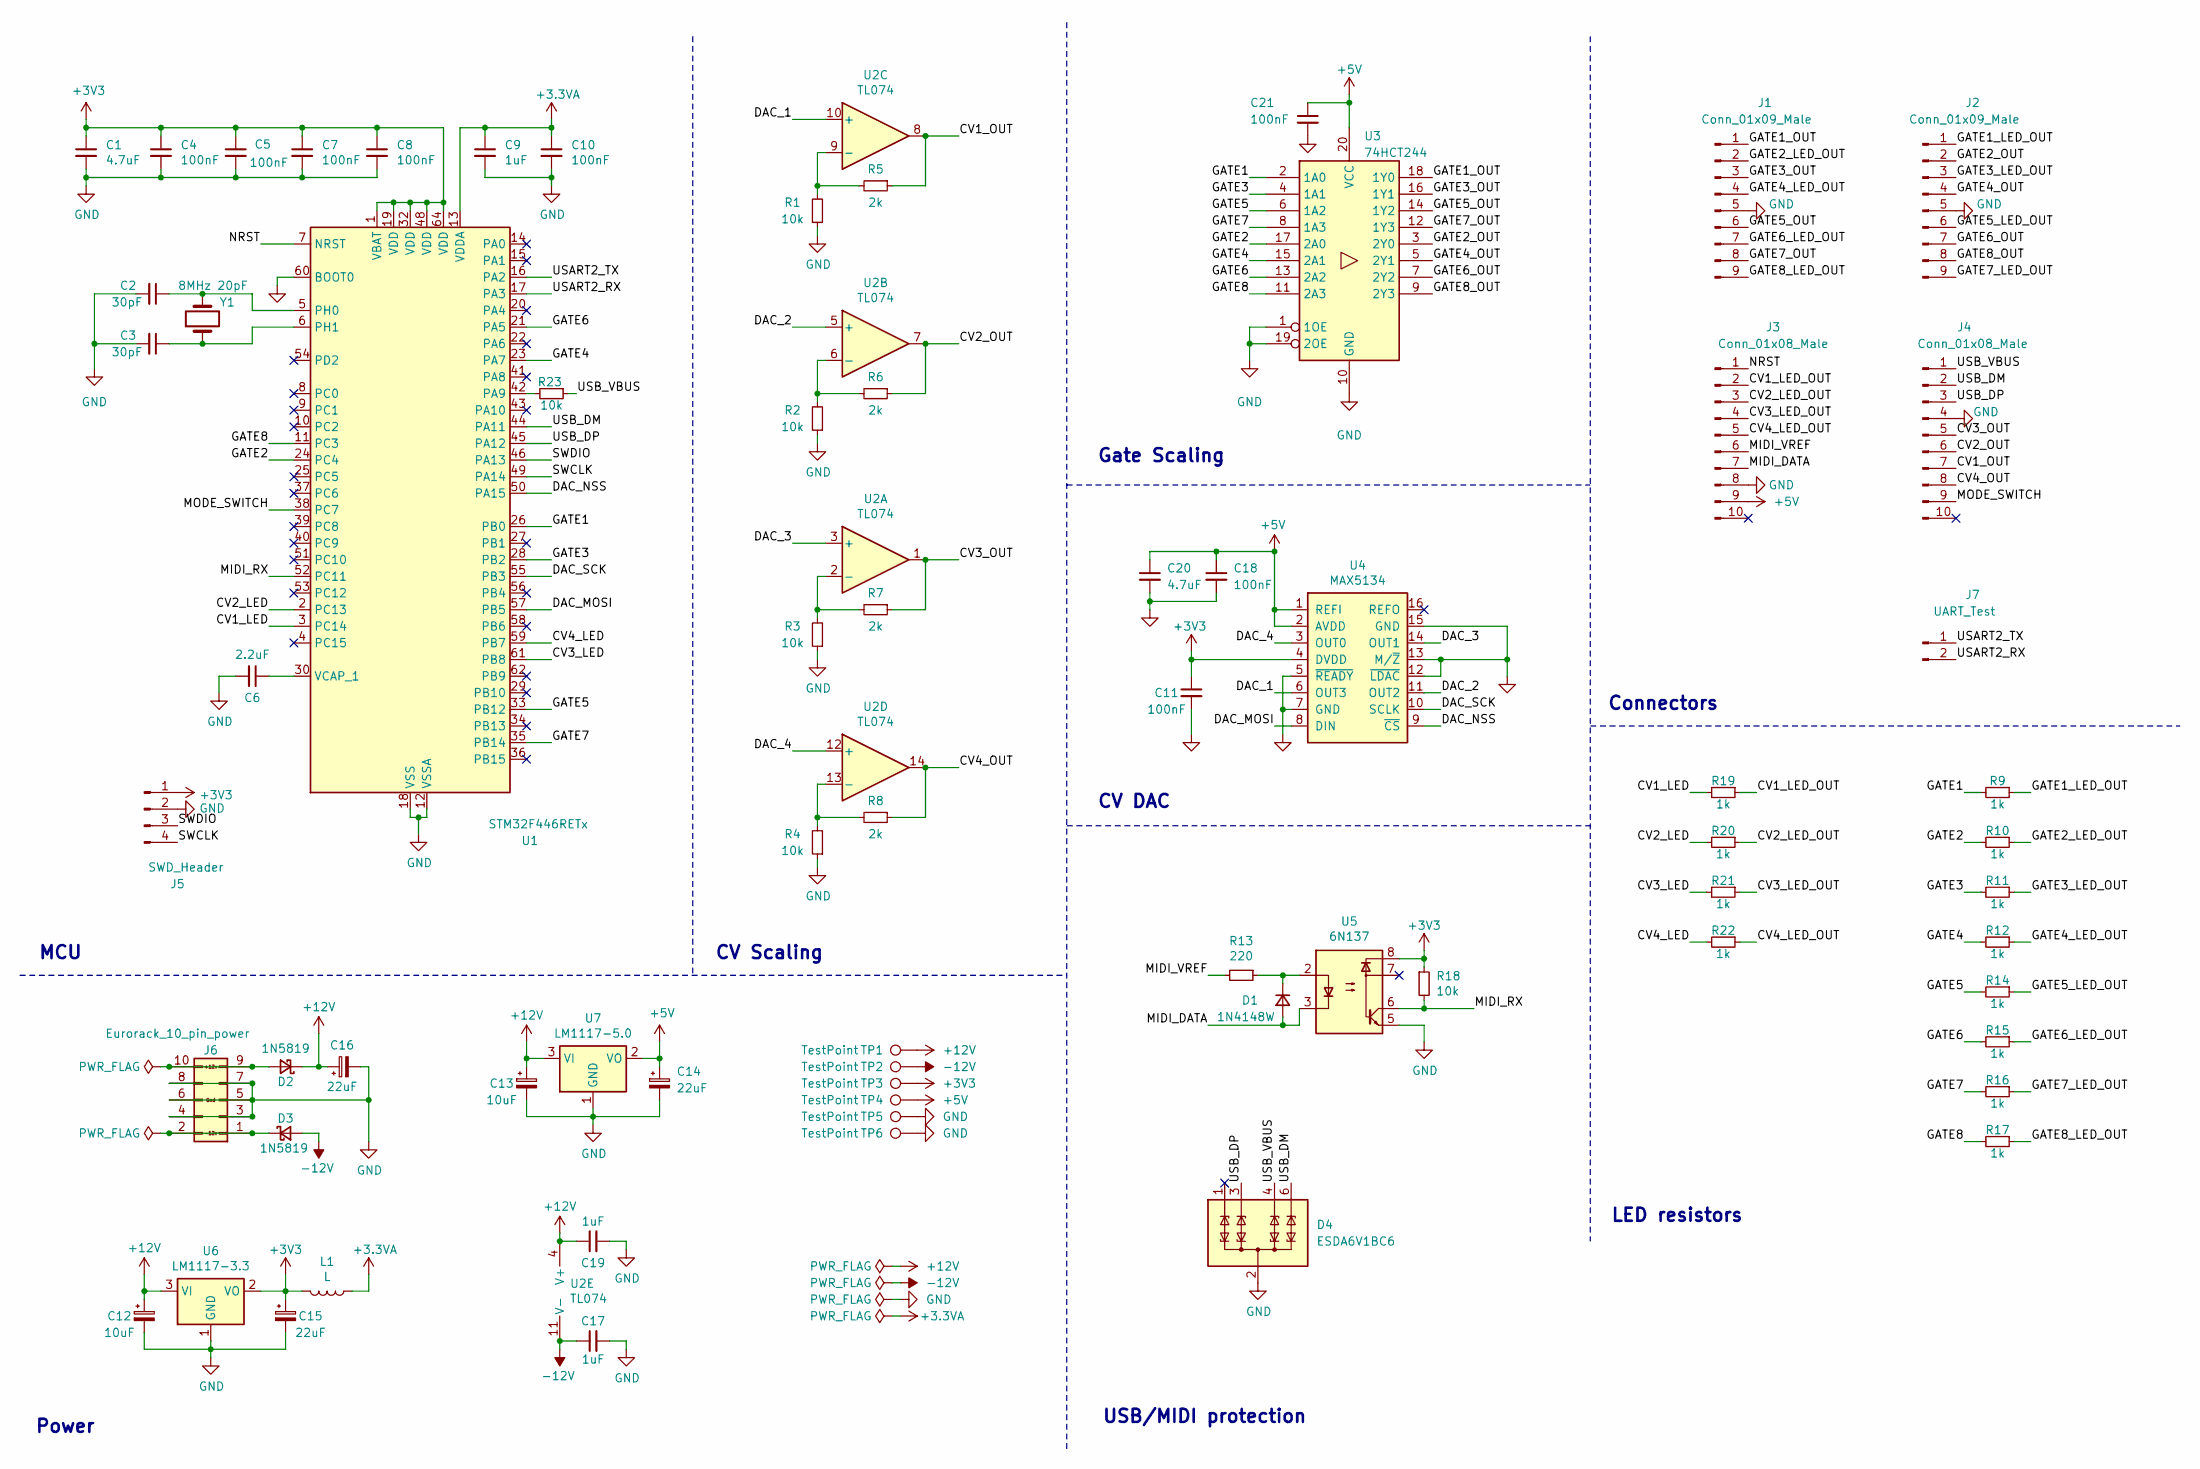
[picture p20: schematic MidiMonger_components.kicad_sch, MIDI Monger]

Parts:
C1, C20: 4.7uF; C_0603_1608Metric
C2, C3: 30pF; C_0603_1608Metric
C4, C5, C7, C8, C10, C11, C18, C21: 100nF; C_0603_1608Metric
C6: 2.2uF; C_0603_1608Metric
C9, C17, C19: 1uF; C_0603_1608Metric
C12, C13: 10uF; C_1206_3216Metric
C14, C15, C16: 22uF; CP_Elec_4x5.8
D1: 1N4148W; D_SOD-123
D2, D3: 1N5819; D_SOD-123
D4: ESDA6V1BC6; SOT-23-6
J1, J2: Conn_01x09_Male; PinHeader_1x09_P2.54mm_Vertical
J3, J4: Conn_01x08_Male; PinHeader_1x10_P2.54mm_Vertical
J5: SWD_Header; SWD_header
J6: Eurorack_10_pin_power; Eurorack_10_pin_header
J7: UART_Test; PinHeader_1x02_P2.54mm_Vertical
L1: L; L_0805_2012Metric_Pad1.05x1.20mm_HandSolder
R1, R2, R3, R4, R18, R23: 10k; R_0603_1608Metric
R5, R6, R7, R8: 2k; R_0603_1608Metric
R9, R10, R11, R12, R14, R15, R16, R17, R19, R20, R21, R22: 1k; R_0603_1608Metric
R13: 220; R_0603_1608Metric
TP1, TP2, TP3, TP4, TP5, TP6: TestPoint; 1mm_Test_Point
U1: STM32F446RETx; LQFP-64_10x10mm_P0.5mm
U2: TL074; SOIC-14_3.9x8.7mm_P1.27mm
U3: 74HCT244; TSSOP-20_4.4x6.5mm_P0.65mm
U4: MAX5134; TSSOP-16_4.4x5mm_P0.65mm
U5: 6N137; DIP-8_W8.89mm_SMDSocket_LongPads
U6: LM1117-3.3; SOT-223-3_TabPin2
U7: LM1117-5.0; SOT-223-3_TabPin2
Y1: 8MHz 20pF; Crystal_SMD_0603-2Pin_6.0x3.5mm; Part_Number C115962

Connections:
+3.3VA: C9.1, C10.1, L1.1, U1.13 (VDDA)
+3V3: C1.1, C4.1, C5.1, C7.1, C8.1, C11.1, C15.1, J5.1, L1.2, R18.1, TP3.1, U1.1 (VBAT), U1.19 (VDD), U1.32 (VDD), U1.48 (VDD), U1.64 (VDD), U4.4 (DVDD), U5.8, U6.2 (VO)
+5V: C14.1, C18.1, C20.1, C21.1, J3.9, TP4.1, U3.20 (VCC), U4.1 (REFI), U4.2 (AVDD), U7.2 (VO)
+12V: C12.1, C13.1, C16.1, C19.1, D2.1 (K), TP1.1, U2.4 (V+), U6.3 (VI), U7.3 (VI)
-12V: C17.1, D3.2 (A), TP2.1, U2.11 (V-)
/CV1_LED: R19.2, U1.3 (PC14)
/CV1_LED_OUT: J3.2, R19.1
/CV1_OUT: J4.7, R5.1, U2.8
/CV2_LED: R20.2, U1.2 (PC13)
/CV2_LED_OUT: J3.3, R20.1
/CV2_OUT: J4.6, R6.1, U2.7
/CV3_LED: R21.2, U1.61 (PB8)
/CV3_LED_OUT: J3.4, R21.1
/CV3_OUT: J4.5, R7.1, U2.1
/CV4_LED: R22.2, U1.59 (PB7)
/CV4_LED_OUT: J3.5, R22.1
/CV4_OUT: J4.8, R8.1, U2.14
/DAC_1: U2.10 (+), U4.6 (OUT3)
/DAC_2: U2.5 (+), U4.11 (OUT2)
/DAC_3: U2.3 (+), U4.14 (OUT1)
/DAC_4: U2.12 (+), U4.3 (OUT0)
/DAC_MOSI: U1.57 (PB5), U4.8 (DIN)
/DAC_NSS: U1.50 (PA15), U4.9 (~CS)
/DAC_SCK: U1.55 (PB3), U4.10 (SCLK)
/GATE1: R9.2, U1.26 (PB0), U3.2 (1A0)
/GATE1_LED_OUT: J2.1, R9.1
/GATE1_OUT: J1.1, U3.18 (1Y0)
/GATE2: R10.2, U1.24 (PC4), U3.17 (2A0)
/GATE2_LED_OUT: J1.2, R10.1
/GATE2_OUT: J2.2, U3.3 (2Y0)
/GATE3: R11.2, U1.28 (PB2), U3.4 (1A1)
/GATE3_LED_OUT: J2.3, R11.1
/GATE3_OUT: J1.3, U3.16 (1Y1)
/GATE4: R12.2, U1.23 (PA7), U3.15 (2A1)
/GATE4_LED_OUT: J1.4, R12.1
/GATE4_OUT: J2.4, U3.5 (2Y1)
/GATE5: R14.2, U1.33 (PB12), U3.6 (1A2)
/GATE5_LED_OUT: J2.6, R14.1
/GATE5_OUT: J1.6, U3.14 (1Y2)
/GATE6: R15.2, U1.21 (PA5), U3.13 (2A2)
/GATE6_LED_OUT: J1.7, R15.1
/GATE6_OUT: J2.7, U3.7 (2Y2)
/GATE7: R16.2, U1.35 (PB14), U3.8 (1A3)
/GATE7_LED_OUT: J2.9, R16.1
/GATE7_OUT: J1.8, U3.12 (1Y3)
/GATE8: R17.2, U1.11 (PC3), U3.11 (2A3)
/GATE8_LED_OUT: J1.9, R17.1
/GATE8_OUT: J2.8, U3.9 (2Y3)
/MIDI_DATA: D1.2 (A), J3.7, U5.3
/MIDI_RX: R18.2, U1.52 (PC11), U5.6
/MIDI_VREF: J3.6, R13.2
/MODE_SWITCH: J4.9, U1.38 (PC7)
/NRST: J3.1, U1.7 (NRST)
/SWCLK: J5.4, U1.49 (PA14)
/SWDIO: J5.3, U1.46 (PA13)
/USART2_RX: J7.2, U1.17 (PA3)
/USART2_TX: J7.1, U1.16 (PA2)
/USB_DM: D4.6 (TVS4), J4.2, U1.44 (PA11)
/USB_DP: D4.3 (TVS2), J4.3, U1.45 (PA12)
/USB_VBUS: D4.4 (TVS3), J4.1, R23.1
GND: C1.2, C2.2, C3.2, C4.2, C5.2, C6.2, C7.2, C8.2, C9.2, C10.2, C11.2, C12.2, C13.2, C14.2, C15.2, C16.2, C17.2, C18.2, C19.2, C20.2, C21.2, D4.2 (COM), D4.5 (COM), J1.5, J2.5, J3.8, J4.4, J5.2, J6.3, J6.4, J6.5, J6.6, J6.7, J6.8, R1.1, R2.1, R3.1, R4.1, TP5.1, TP6.1, U1.12 (VSSA), U1.18 (VSS), U1.31 (VSS), U1.47 (VSS), U1.60 (BOOT0), U1.63 (VSS), U3.1 (1OE), U3.10 (GND), U3.19 (2OE), U4.5 (~READY), U4.7 (GND), U4.12 (~LDAC), U4.13 (M/~Z), U4.15 (GND), U5.5, U6.1 (GND), U7.1 (GND)
unnamed: D1.1 (K), R13.1, U5.2
unnamed: D2.2 (A), J6.9, J6.10
unnamed: D3.1 (K), J6.1, J6.2
unnamed: R23.2, U1.42 (PA9)
unnamed: C2.1, U1.5 (PH0), Y1.2
unnamed: C3.1, U1.6 (PH1), Y1.1
unnamed: C6.1, U1.30 (VCAP_1)
unnamed: R3.2, R7.2, U2.2 (-)
unnamed: R2.2, R6.2, U2.6 (-)
unnamed: R1.2, R5.2, U2.9 (-)
unnamed: R4.2, R8.2, U2.13 (-)

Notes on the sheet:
CV DAC
LED resistors
Connectors
Gate Scaling
USB/MIDI protection
CV Scaling
Power
MCU

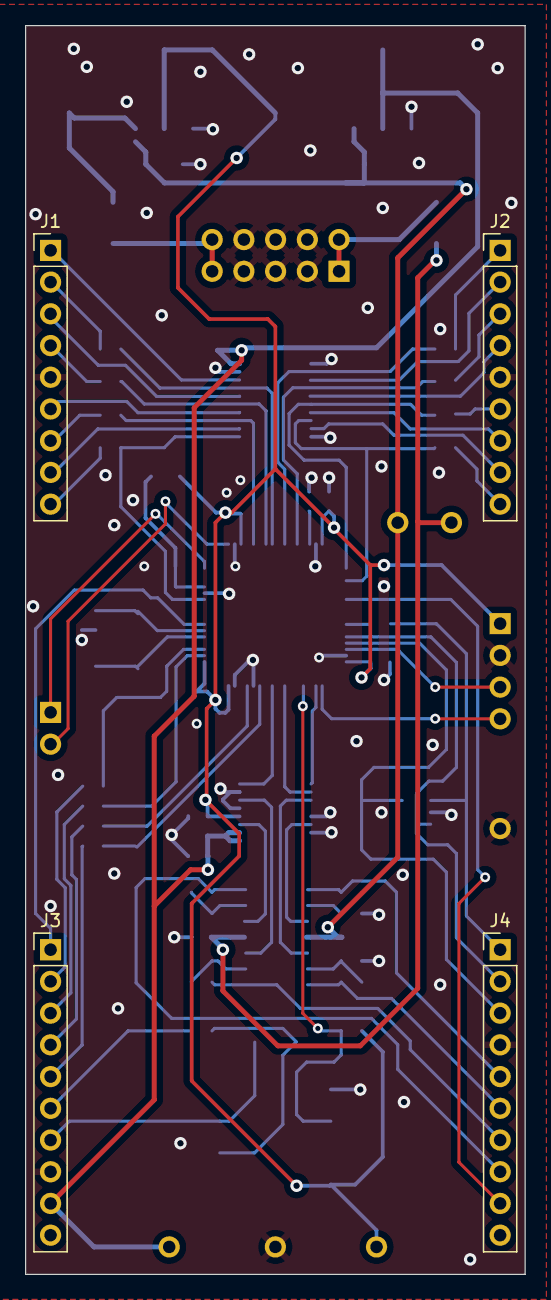
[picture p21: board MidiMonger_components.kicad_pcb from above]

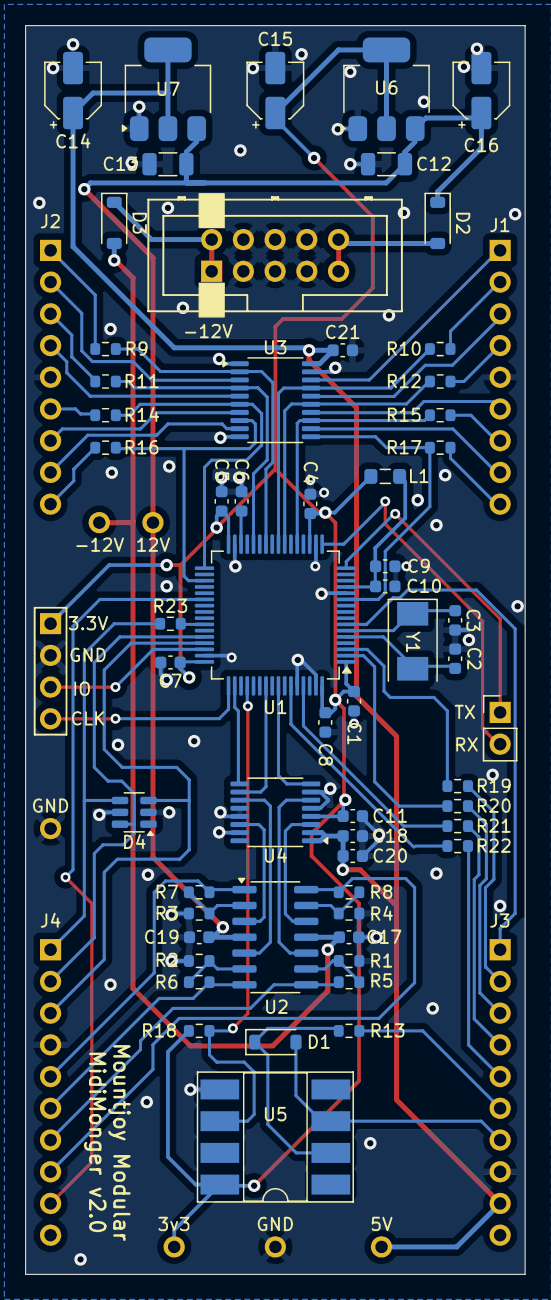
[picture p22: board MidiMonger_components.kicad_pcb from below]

Board: 2 copper layers, 40.0 x 100.0 mm, 70 parts (66 on the bottom side), 72 nets.

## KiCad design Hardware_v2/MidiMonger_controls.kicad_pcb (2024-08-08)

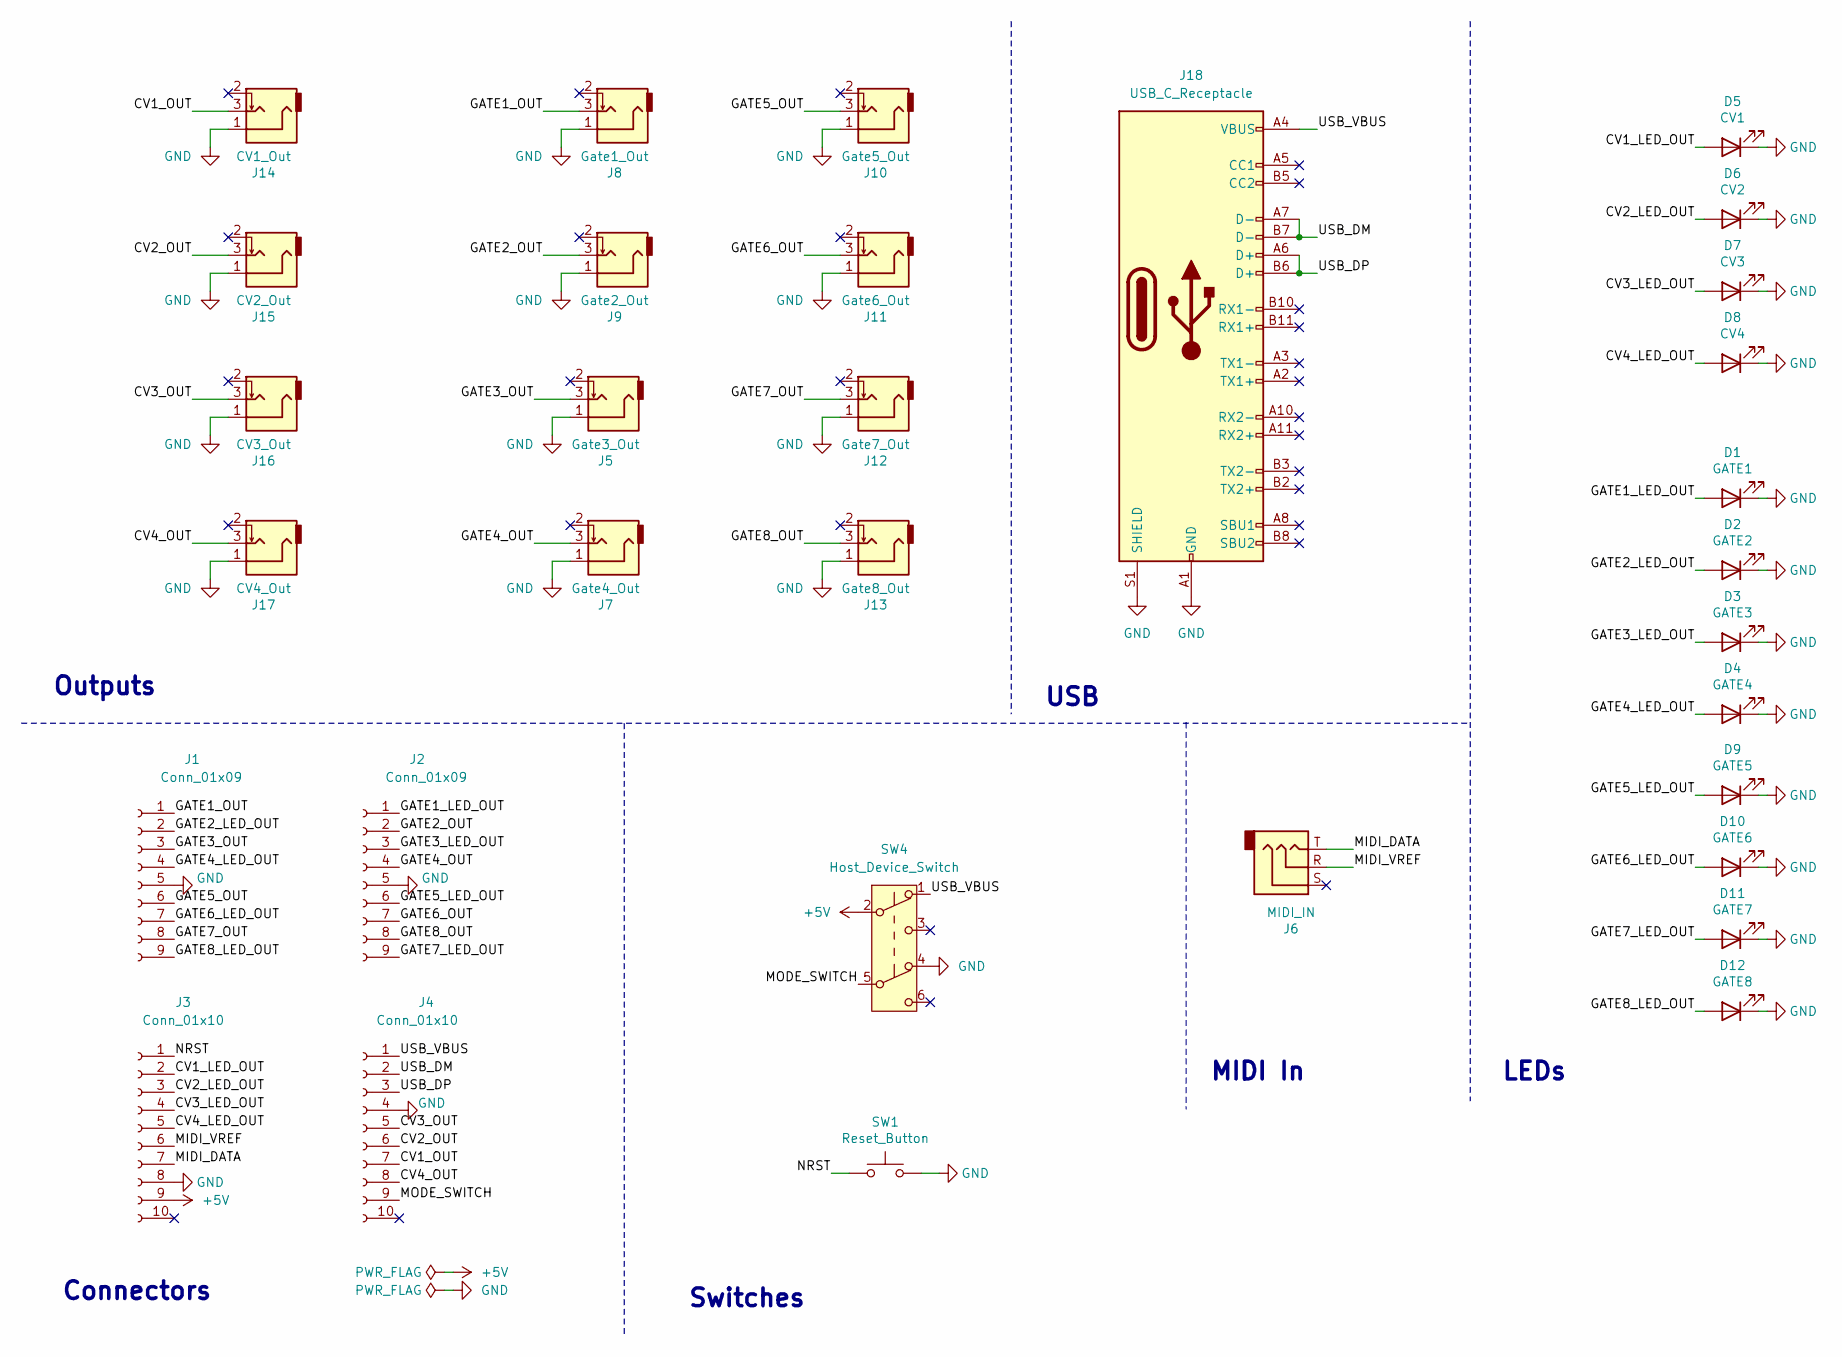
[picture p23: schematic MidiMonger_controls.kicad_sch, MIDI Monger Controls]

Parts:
D1: GATE1; LED_D3.0mm
D2: GATE2; LED_D3.0mm
D3: GATE3; LED_D3.0mm
D4: GATE4; LED_D3.0mm
D5: CV1; LED_D3.0mm
D6: CV2; LED_D3.0mm
D7: CV3; LED_D3.0mm
D8: CV4; LED_D3.0mm
D9: GATE5; LED_D3.0mm
D10: GATE6; LED_D3.0mm
D11: GATE7; LED_D3.0mm
D12: GATE8; LED_D3.0mm
J1, J2: Conn_01x09; PinSocket_1x09_P2.54mm_Vertical
J3, J4: Conn_01x10; PinSocket_1x10_P2.54mm_Vertical
J5: Gate3_Out; THONKICONN_hole
J6: MIDI_IN; Thonkiconn_Stereo-PJ366ST
J7: Gate4_Out; THONKICONN_hole
J8: Gate1_Out; THONKICONN_hole
J9: Gate2_Out; THONKICONN_hole
J10: Gate5_Out; THONKICONN_hole
J11: Gate6_Out; THONKICONN_hole
J12: Gate7_Out; THONKICONN_hole
J13: Gate8_Out; THONKICONN_hole
J14: CV1_Out; THONKICONN_hole
J15: CV2_Out; THONKICONN_hole
J16: CV3_Out; THONKICONN_hole
J17: CV4_Out; THONKICONN_hole
J18: USB_C_Receptacle; USB_C_Receptacle_Amphenol_12401951E412A
SW1: Reset_Button; SW_PUSH_6mm
SW4: Host_Device_Switch; 100DP6T1B1M2QE_ON_ON_ON

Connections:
+5V: J3.9, SW4.2 (B)
/CV1_LED_OUT: D5.2 (A), J3.2
/CV1_OUT: J4.7, J14.3
/CV2_LED_OUT: D6.2 (A), J3.3
/CV2_OUT: J4.6, J15.3
/CV3_LED_OUT: D7.2 (A), J3.4
/CV3_OUT: J4.5, J16.3
/CV4_LED_OUT: D8.2 (A), J3.5
/CV4_OUT: J4.8, J17.3
/GATE1_LED_OUT: D1.2 (A), J2.1
/GATE1_OUT: J1.1, J8.3
/GATE2_LED_OUT: D2.2 (A), J1.2
/GATE2_OUT: J2.2, J9.3
/GATE3_LED_OUT: D3.2 (A), J2.3
/GATE3_OUT: J1.3, J5.3
/GATE4_LED_OUT: D4.2 (A), J1.4
/GATE4_OUT: J2.4, J7.3
/GATE5_LED_OUT: D9.2 (A), J2.6
/GATE5_OUT: J1.6, J10.3
/GATE6_LED_OUT: D10.2 (A), J1.7
/GATE6_OUT: J2.7, J11.3
/GATE7_LED_OUT: D11.2 (A), J2.9
/GATE7_OUT: J1.8, J12.3
/GATE8_LED_OUT: D12.2 (A), J1.9
/GATE8_OUT: J2.8, J13.3
/MIDI_DATA: J3.7, J6.T
/MIDI_VREF: J3.6, J6.R
/MODE_SWITCH: J4.9, SW4.5 (B)
/NRST: J3.1, SW1.1
/USB_DM: J4.2, J18.A7 (D-), J18.B7 (D-)
/USB_DP: J4.3, J18.A6 (D+), J18.B6 (D+)
/USB_VBUS: J4.1, J18.A4 (VBUS), J18.A9 (VBUS), J18.B4 (VBUS), J18.B9 (VBUS), SW4.1 (A)
GND: D1.1 (K), D2.1 (K), D3.1 (K), D4.1 (K), D5.1 (K), D6.1 (K), D7.1 (K), D8.1 (K), D9.1 (K), D10.1 (K), D11.1 (K), D12.1 (K), J1.5, J2.5, J3.8, J4.4, J5.1, J7.1, J8.1, J9.1, J10.1, J11.1, J12.1, J13.1, J14.1, J15.1, J16.1, J17.1, J18.A1 (GND), J18.A12 (GND), J18.B1 (GND), J18.B12 (GND), J18.S1 (SHIELD), SW1.2, SW4.4 (A)

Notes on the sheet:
Outputs
Switches
USB
MIDI In
LEDs
Connectors

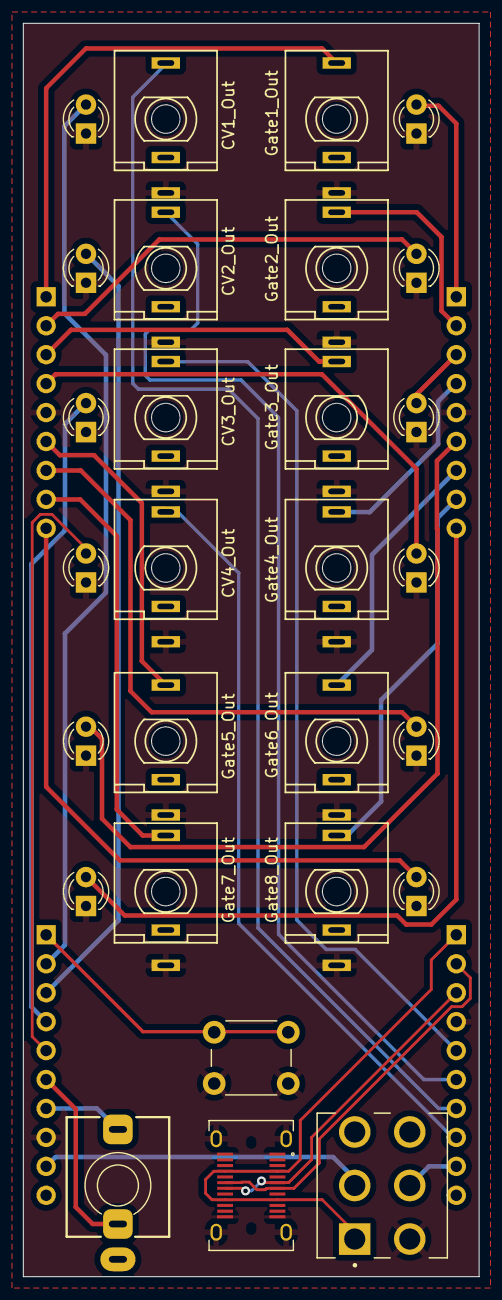
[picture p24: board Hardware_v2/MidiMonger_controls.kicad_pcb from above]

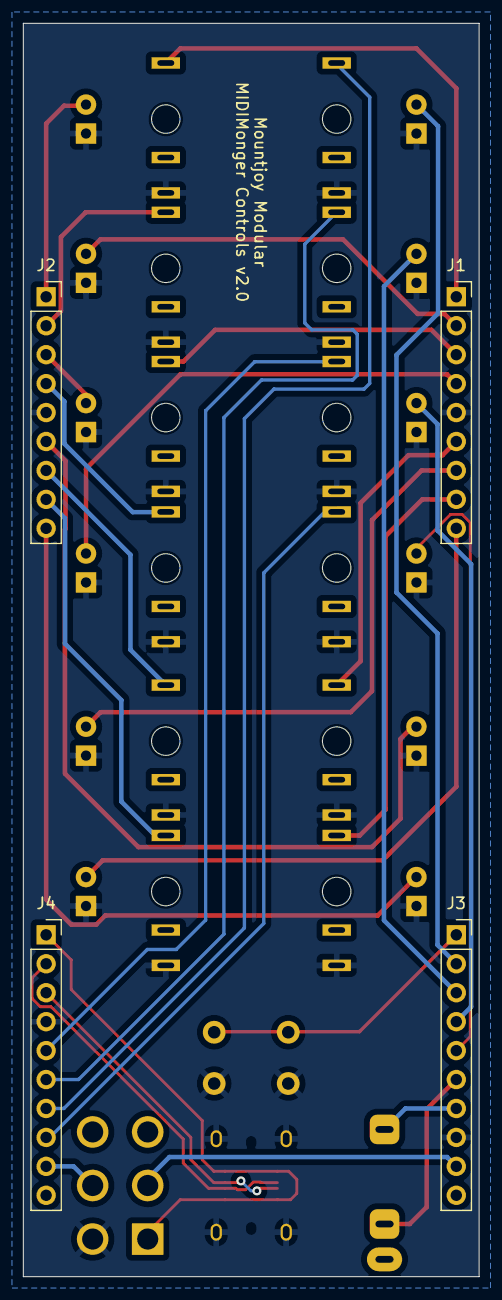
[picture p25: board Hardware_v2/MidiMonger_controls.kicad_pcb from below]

Board: 2 copper layers, 40.0 x 110.0 mm, 32 parts (4 on the bottom side), 33 nets.

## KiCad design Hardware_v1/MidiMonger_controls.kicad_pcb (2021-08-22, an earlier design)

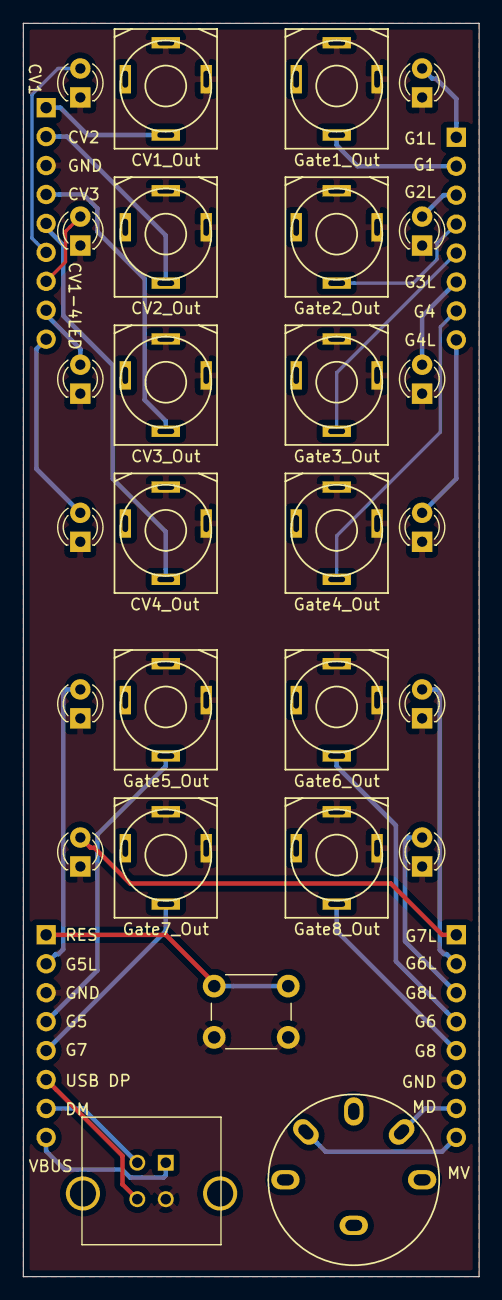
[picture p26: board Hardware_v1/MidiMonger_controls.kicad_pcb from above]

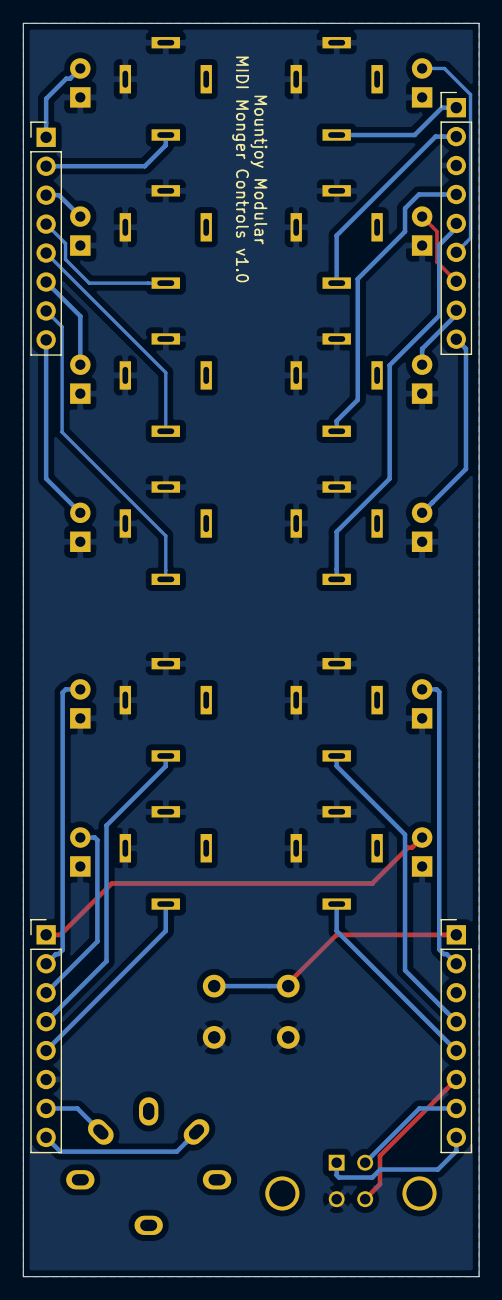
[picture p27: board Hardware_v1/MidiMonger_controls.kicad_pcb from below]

Board: 2 copper layers, 40.0 x 110.0 mm, 31 parts (4 on the bottom side), 31 nets.

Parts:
D1: GATE1; LED_D3.0mm
D2: GATE2; LED_D3.0mm
D3: GATE3; LED_D3.0mm
D4: GATE4; LED_D3.0mm
D5: CV1; LED_D3.0mm
D6: CV2; LED_D3.0mm
D7: CV3; LED_D3.0mm
D8: CV4; LED_D3.0mm
D9: GATE5; LED_D3.0mm
D10: GATE6; LED_D3.0mm
D11: GATE7; LED_D3.0mm
D12: GATE8; LED_D3.0mm
J2: Gate3_Out; Cliff_3.5mm_Stereo_Jack
J3: Gate4_Out; Cliff_3.5mm_Stereo_Jack
J4: Gate1_Out; Cliff_3.5mm_Stereo_Jack
J5: Gate2_Out; Cliff_3.5mm_Stereo_Jack
J7: Gate5_Out; Cliff_3.5mm_Stereo_Jack
J8: Gate6_Out; Cliff_3.5mm_Stereo_Jack
J9: Gate7_Out; Cliff_3.5mm_Stereo_Jack
J10: Gate8_Out; Cliff_3.5mm_Stereo_Jack
J11: CV1_Out; Cliff_3.5mm_Stereo_Jack
J12: CV2_Out; Cliff_3.5mm_Stereo_Jack
J13: CV3_Out; Cliff_3.5mm_Stereo_Jack
J14: CV4_Out; Cliff_3.5mm_Stereo_Jack
J15: USB_B_Wurth
J16: MIDI_DIN
J20: Conn_01x09_Female; Socket_Strip_Straight_1x09_Pitch2.54mm
J21, J22, J23: Conn_01x08_Female; Socket_Strip_Straight_1x08_Pitch2.54mm
SW1: SW_Push; SW_PUSH_6mm

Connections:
CV1_LED_OUT: D5.2, J20.6
CV1_OUT: J11.3, J20.1
CV2_LED_OUT: D6.2, J20.7
CV2_OUT: J12.3, J20.2
CV3_LED_OUT: D7.2, J20.8
CV3_OUT: J13.3, J20.4
CV4_LED_OUT: D8.2, J20.9
CV4_OUT: J14.3, J20.5
GATE1_LED_OUT: D1.2, J21.1
GATE1_OUT: J4.3, J21.2
GATE2_LED_OUT: D2.2, J21.3
GATE2_OUT: J5.3, J21.4
GATE3_LED_OUT: D3.2, J21.6
GATE3_OUT: J2.3, J21.5
GATE4_LED_OUT: D4.2, J21.8
GATE4_OUT: J3.3, J21.7
GATE5_LED_OUT: D9.2, J22.2
GATE5_OUT: J7.3, J22.4
GATE6_LED_OUT: D10.2, J23.2
GATE6_OUT: J8.3, J23.4
GATE7_LED_OUT: D11.2, J23.1
GATE7_OUT: J9.3, J22.5
GATE8_LED_OUT: D12.2, J23.3
GATE8_OUT: J10.3, J23.5
GND: D1.1, D2.1, D3.1, D4.1, D5.1, D6.1, D7.1, D8.1, D9.1, D10.1, D11.1, D12.1, J2.1, J3.1, J4.1, J5.1, J7.1, J8.1, J9.1, J10.1, J11.1, J12.1, J13.1, J14.1, J15.4, J20.3, J22.3, J23.6, SW1.2
MIDI_DATA: J16.5, J23.7
MIDI_VREF: J16.4, J23.8
RESET_SWITCH: J22.1, SW1.1
USB_DM: J15.2, J22.7
USB_DP: J15.3, J22.6
USB_VBUS: J15.1, J22.8

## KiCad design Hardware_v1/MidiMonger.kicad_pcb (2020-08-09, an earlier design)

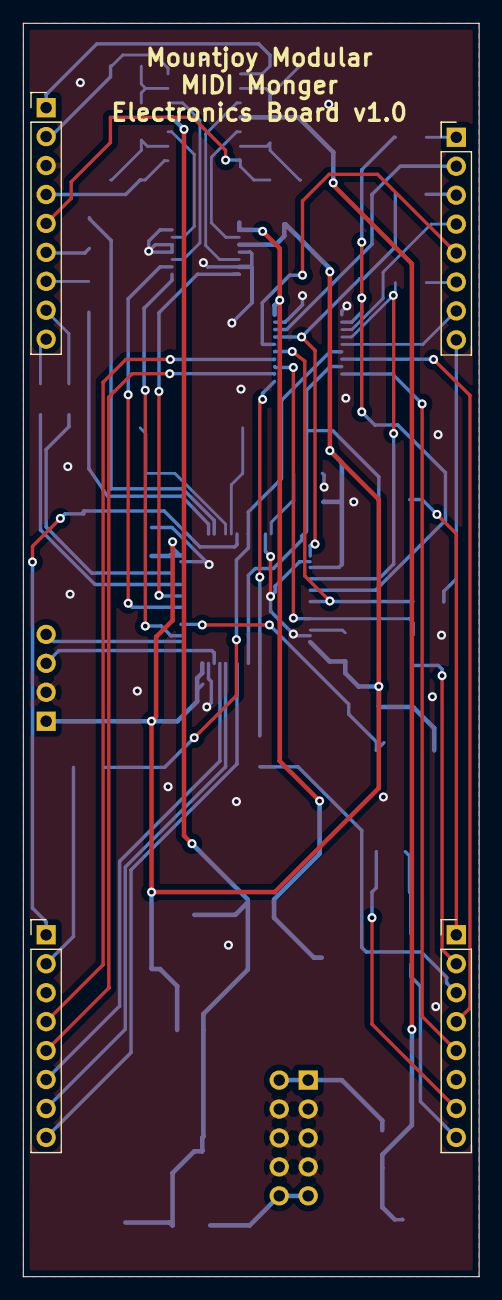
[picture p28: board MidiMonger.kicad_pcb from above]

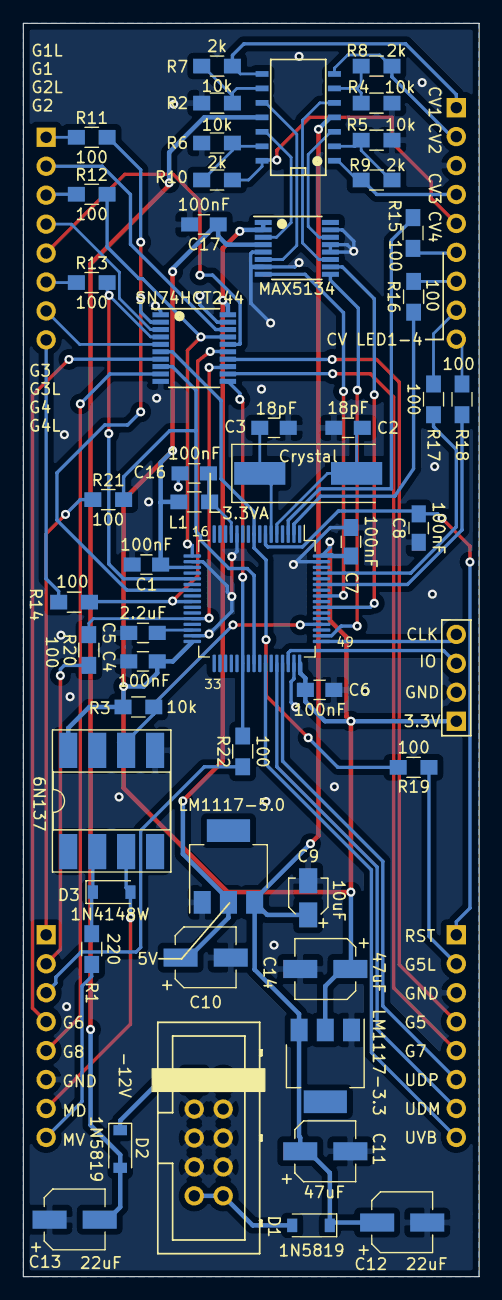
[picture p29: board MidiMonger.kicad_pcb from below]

Board: 2 copper layers, 40.0 x 110.0 mm, 56 parts (52 on the bottom side), 68 nets.

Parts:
C1, C4, C6, C7, C8, C16, C17: 100nF; C_0805_HandSoldering
C2, C3: 18pF; C_0805_HandSoldering
C5: 2.2uF; C_0805_HandSoldering
C9: 10uF; CP_Elec_3x5.3
C10, C12, C13: 22uF; CP_Elec_5x5.3
C11, C14: 47uF; CP_Elec_5x5.8
D1, D2: 1N5819; D_SOD-123
D3: 1N4148W; D_SOD-123
J1: SWD_Header; SWD_header
J2: Conn_01x09_Male; Socket_Strip_Straight_1x09_Pitch2.54mm
J3, J4, J5: Conn_01x08_Male; Socket_Strip_Straight_1x08_Pitch2.54mm
J9: Eurorack_10_pin_power; Eurorack_10_pin_header
L1: L; L_0805_HandSoldering
R1: 220; R_0805_HandSoldering
R2, R3, R4, R5, R6: 10k; R_0805_HandSoldering
R7, R8, R9, R10: 2k; R_0805_HandSoldering
R11, R12, R13, R14, R15, R16, R17, R18, R19, R20, R21, R22: 100; R_0805_HandSoldering
U1: STM32F446RETx; LQFP-64_10x10mm_P0.5mm
U2: 6N137; DIP-8_W8.89mm_SMDSocket_LongPads
U3: TL074; SOIC-14_N
U4: LM1117-5.0; SOT-223
U5: LM1117-3.3; SOT-223
U6: SN74HCT244; TSSOP-20_4.4x6.5mm_Pitch0.65mm
U7: MAX5134; TSSOP-16_4.4x5mm_Pitch0.65mm
Y1: Crystal; Crystal_SMD

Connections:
+3.3VA: C16.1, L1.1, U1.13
+3V3: C1.1, C4.1, C6.1, C7.1, C14.1, C17.1, J1.1, L1.2, R3.1, U1.19, U1.32, U1.48, U1.64, U2.8, U5.2, U7.4
+5V: C10.1, U4.2, U6.20, U7.1, U7.2
+12V: D1.2, J9.9, J9.10
-12V: D2.1, J9.1, J9.2
CV1_LED: R15.2, U1.3
CV1_LED_OUT: J2.6, R15.1
CV1_OUT: J2.1, R7.1, U3.8
CV2_LED: R16.2, U1.2
CV2_LED_OUT: J2.7, R16.1
CV2_OUT: J2.2, R8.1, U3.7
CV3_LED: R17.2, U1.61
CV3_LED_OUT: J2.8, R17.1
CV3_OUT: J2.4, R9.1, U3.1
CV4_LED: R18.2, U1.59
CV4_LED_OUT: J2.9, R18.1
CV4_OUT: J2.5, R10.1, U3.14
DAC_1: U3.10, U7.6
DAC_2: U3.5, U7.11
DAC_3: U3.3, U7.14
DAC_4: U3.12, U7.3
DAC_MOSI: U1.57, U7.8
DAC_NSS: U1.50, U7.9
DAC_SCK: U1.55, U7.10
GATE1: R11.2, U1.23, U6.2
GATE1_LED_OUT: J3.1, R11.1
GATE1_OUT: J3.2, U6.18
GATE2: R12.2, U1.17, U6.17
GATE2_LED_OUT: J3.3, R12.1
GATE2_OUT: J3.4, U6.3
GATE3: R13.2, U1.21, U6.4
GATE3_LED_OUT: J3.6, R13.1
GATE3_OUT: J3.5, U6.16
GATE4: R14.2, U1.25, U6.15
GATE4_LED_OUT: J3.8, R14.1
GATE4_OUT: J3.7, U6.5
GATE5: R19.2, U1.9, U6.6
GATE5_LED_OUT: J4.2, R19.1
GATE5_OUT: J4.4, U6.14
GATE6: R20.2, U1.28, U6.13
GATE6_LED_OUT: J5.2, R20.1
GATE6_OUT: J5.4, U6.7
GATE7: R21.2, U1.40, U6.8
GATE7_LED_OUT: J5.1, R21.1
GATE7_OUT: J4.5, U6.12
GATE8: R22.2, U1.38, U6.11
GATE8_LED_OUT: J5.3, R22.1
GATE8_OUT: J5.5, U6.9
GND: C1.2, C2.2, C3.2, C4.2, C5.2, C6.2, C7.2, C8.1, C9.2, C10.2, C11.2, C12.2, C13.1, C14.2, C16.2, C17.2, J1.2, J2.3, J4.3, J5.6, J9.3, J9.4, J9.5, J9.6, J9.7, J9.8, R2.1, R4.1, R5.1, R6.1, U1.12, U1.18, U1.31, U1.47, U1.63, U2.5, U4.1, U5.1, U6.1, U6.10, U6.19, U7.5, U7.7, U7.12, U7.13, U7.15
MIDI_DATA: D3.2, J5.7, U2.3
MIDI_RX: R3.2, U1.52, U2.6
MIDI_VREF: J5.8, R1.2
NRST: C8.2, J4.1, U1.7
unnamed: C2.1, U1.5, Y1.2
unnamed: C3.1, U1.6, Y1.1
unnamed: C5.1, U1.30
unnamed: D3.1, R1.1, U2.2
unnamed: R2.2, R7.2, U3.9
unnamed: R4.2, R8.2, U3.6
unnamed: R5.2, R9.2, U3.2
unnamed: R6.2, R10.2, U3.13
SWCLK: J1.4, U1.49
SWDIO: J1.3, U1.46
USB_DM: J4.7, U1.44
USB_DP: J4.6, U1.45
USB_VBUS: J4.8, U1.42
VCC: C9.1, C11.1, C12.1, D1.1, U3.4, U4.3, U5.3
VEE: C13.2, D2.2, U3.11

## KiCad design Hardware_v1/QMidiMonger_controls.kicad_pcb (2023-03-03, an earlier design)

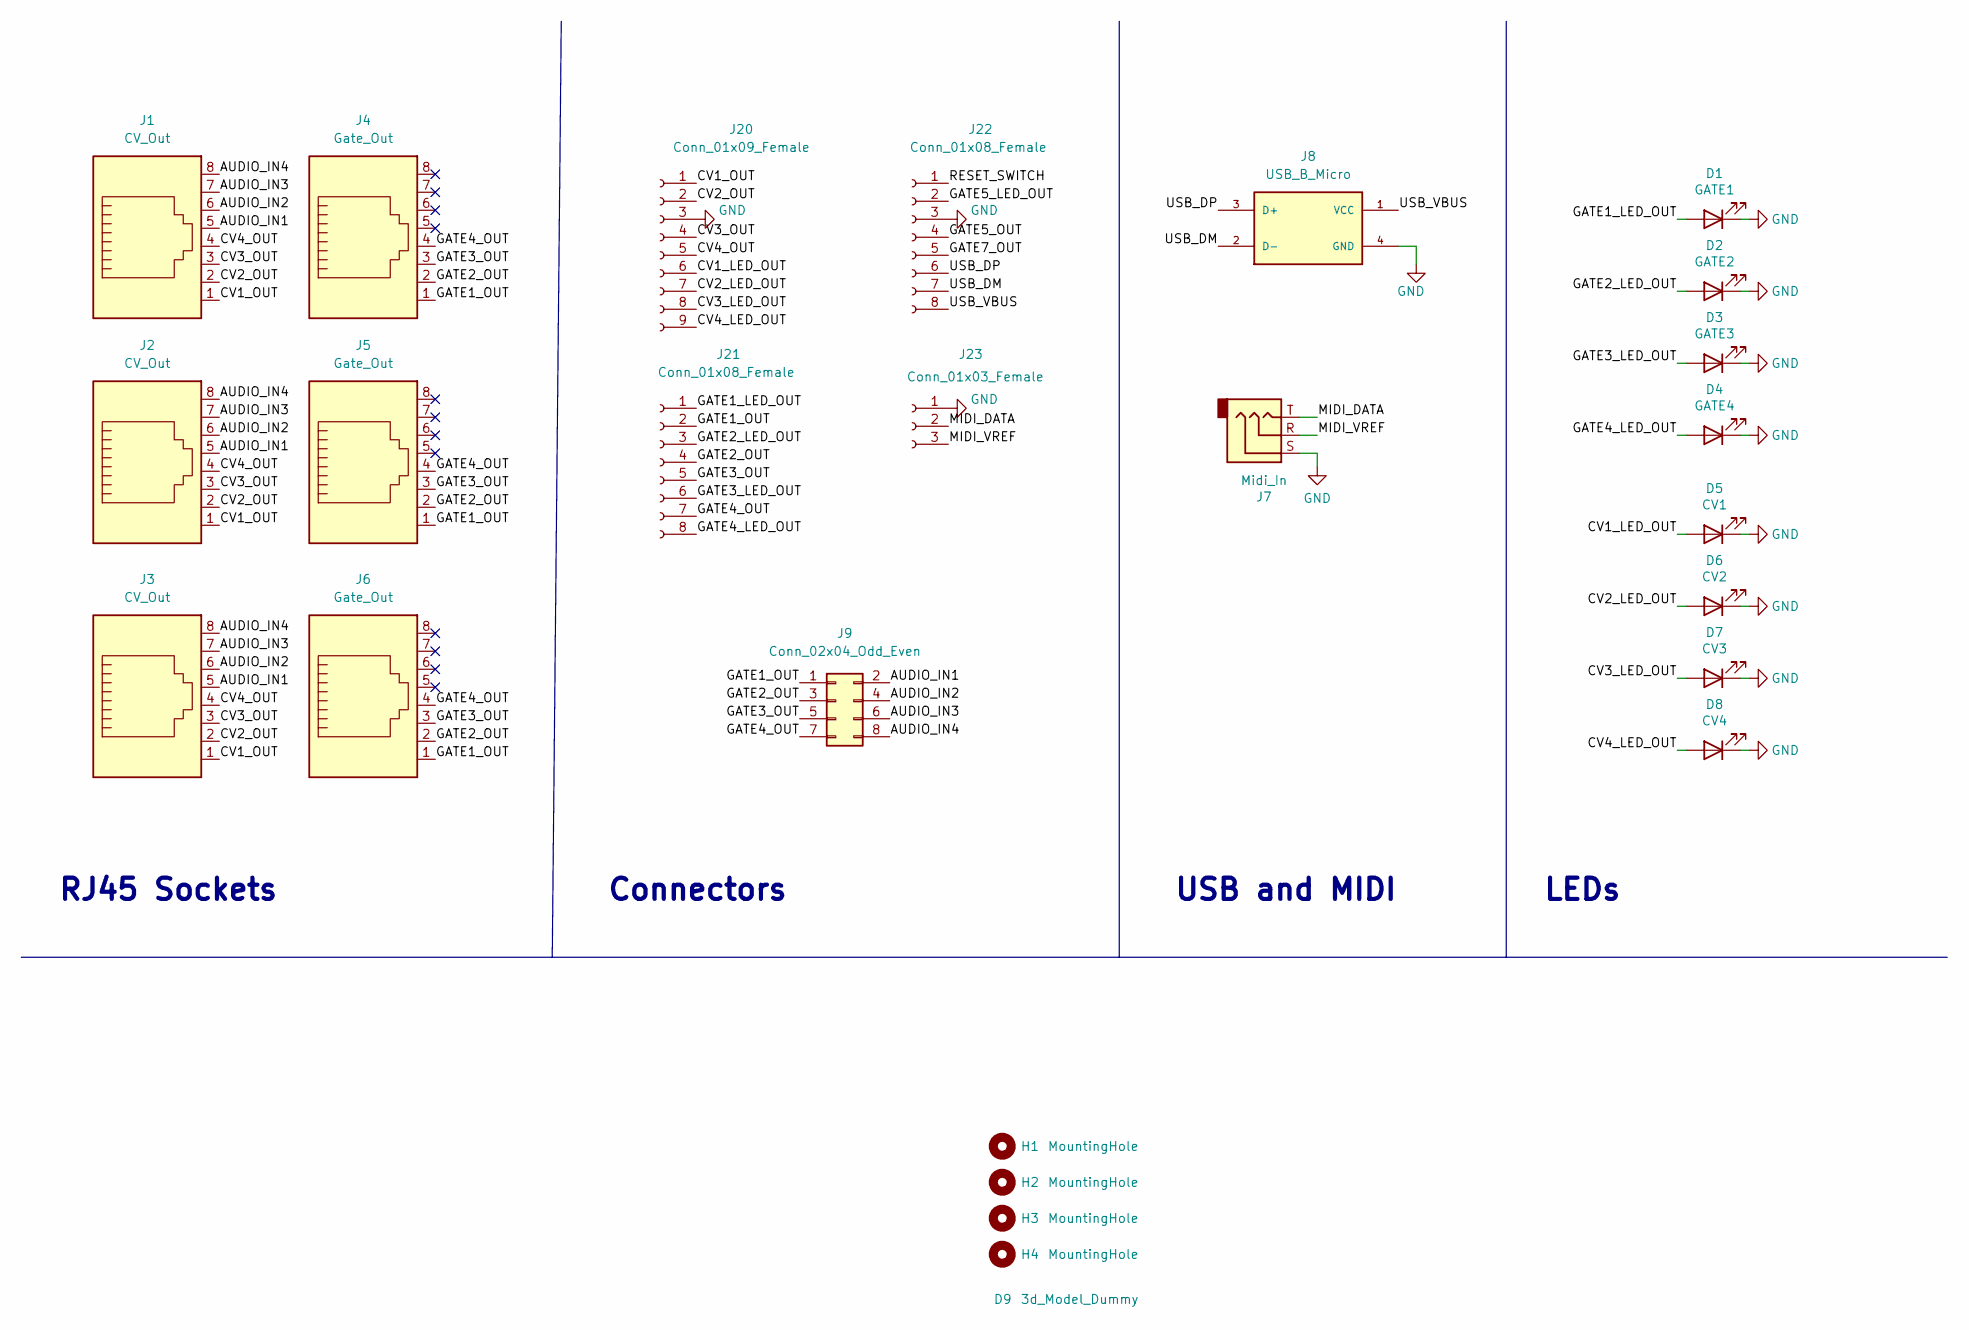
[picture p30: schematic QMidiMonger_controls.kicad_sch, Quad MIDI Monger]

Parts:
D1: GATE1; LED_D3.0mm
D2: GATE2; LED_D3.0mm
D3: GATE3; LED_D3.0mm
D4: GATE4; LED_D3.0mm
D5: CV1; LED_D3.0mm
D6: CV2; LED_D3.0mm
D7: CV3; LED_D3.0mm
D8: CV4; LED_D3.0mm
D9: 3d_Model_Dummy; 3D_Dummy
H1, H2, H3, H4: MountingHole; MountingHole_3.2mm_M3_ISO14580
J1, J2, J3: CV_Out; RJ45_Molex_42878-8506
J4, J5, J6: Gate_Out; RJ45_Molex_42878-8506
J7: Midi_In; Thonkiconn_Stereo-PJ366ST
J8: USB_B_Micro; USB_TE_1734517-1
J9: Conn_02x04_Odd_Even; PinHeader_2x04_P2.54mm_Vertical
J20: Conn_01x09_Female; Socket_Strip_Straight_1x09_Pitch2.54mm
J21, J22: Conn_01x08_Female; Socket_Strip_Straight_1x08_Pitch2.54mm
J23: Conn_01x03_Female; PinHeader_1x03_P2.54mm_Vertical

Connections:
/AUDIO_IN1: J1.5, J2.5, J3.5, J9.2
/AUDIO_IN2: J1.6, J2.6, J3.6, J9.4
/AUDIO_IN3: J1.7, J2.7, J3.7, J9.6
/AUDIO_IN4: J1.8, J2.8, J3.8, J9.8
/CV1_LED_OUT: D5.2 (A), J20.6
/CV1_OUT: J1.1, J2.1, J3.1, J20.1
/CV2_LED_OUT: D6.2 (A), J20.7
/CV2_OUT: J1.2, J2.2, J3.2, J20.2
/CV3_LED_OUT: D7.2 (A), J20.8
/CV3_OUT: J1.3, J2.3, J3.3, J20.4
/CV4_LED_OUT: D8.2 (A), J20.9
/CV4_OUT: J1.4, J2.4, J3.4, J20.5
/GATE1_LED_OUT: D1.2 (A), J21.1
/GATE1_OUT: J4.1, J5.1, J6.1, J9.1, J21.2
/GATE2_LED_OUT: D2.2 (A), J21.3
/GATE2_OUT: J4.2, J5.2, J6.2, J9.3, J21.4
/GATE3_LED_OUT: D3.2 (A), J21.6
/GATE3_OUT: J4.3, J5.3, J6.3, J9.5, J21.5
/GATE4_LED_OUT: D4.2 (A), J21.8
/GATE4_OUT: J4.4, J5.4, J6.4, J9.7, J21.7
/GATE5_LED_OUT: J22.2
/GATE5_OUT: J22.4
/GATE7_OUT: J22.5
/MIDI_DATA: J7.T, J23.2
/MIDI_VREF: J7.R, J23.3
/RESET_SWITCH: J22.1
/USB_DM: J8.2 (D-), J22.7
/USB_DP: J8.3 (D+), J22.6
/USB_VBUS: J8.1 (VCC), J22.8
GND: D1.1 (K), D2.1 (K), D3.1 (K), D4.1 (K), D5.1 (K), D6.1 (K), D7.1 (K), D8.1 (K), J7.S, J8.4 (GND), J20.3, J22.3, J23.1

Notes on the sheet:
RJ45 Sockets
LEDs
USB and MIDI
Connectors

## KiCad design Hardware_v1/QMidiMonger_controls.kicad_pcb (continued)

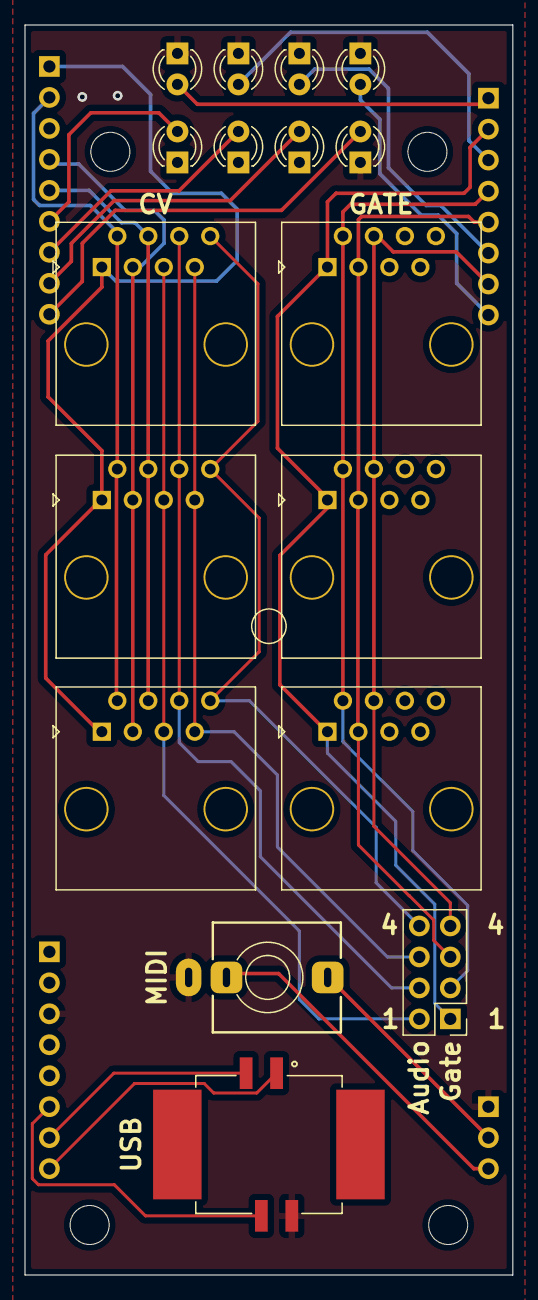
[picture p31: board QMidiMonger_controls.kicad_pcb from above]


Board: 2 copper layers, 40.0 x 102.5 mm, 26 parts (4 on the bottom side), 26 nets.

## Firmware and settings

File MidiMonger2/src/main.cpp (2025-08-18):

#include "initialisation.h"
#include "USBHost.h"
#include "USB.h"
#include "HidHostClass.h"
#include "CommandHandler.h"
#include "uartHandler.h"
#include "configManager.h"
#include "MidiControl.h"
#include <stdio.h>

volatile uint32_t SysTickVal;
bool hostMode = true;

extern "C" {
#include "interrupts.h"
}

Config config{&midiControl.configSaver, &hidHostClass.configSaver};		// Construct config handler with list of configSavers


int main(void)
{
	InitHardware();
	uart.Init();
	dacHandler.Init();
	config.RestoreConfig();

	hostMode = modeSwitch.IsLow();
	if (hostMode) {
		usbHost.Init();
	} else {
		usb.Init(false);
	}

	printf("\r\n\r\nStarting ...\r\n");
	midiControl.LightShow(MidiControl::LightShowType::startup);

	while (1) {
		midiControl.GateTimer();			// Switches off any pending gates/leds
		config.SaveConfig();				// Save any scheduled changes
		commandHandler.CheckCommands();		// Check if any commands received via USB serial or UART

		if (hostMode) {
			usbHost.Process();
		}

		if (modeSwitch.IsLow() != hostMode) {			// Switch between USB host and device mode
			DelayMS(2);
			if (modeSwitch.IsHigh()) {
				printf("Switching to device mode\r\n");
				usbHost.Disable();
				hostMode = false;
				DelayMS(10);
				usb.Init(false);
			} else {
				printf("Switching to host mode\r\n");
				usb.Disable();
				DelayMS(10);
				hostMode = true;
				usbHost.Init();
			}
		}
	}
}

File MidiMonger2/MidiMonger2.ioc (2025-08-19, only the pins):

Mcu.UserName=STM32F446RETx
PA11.Signal=USB_OTG_FS_DM
PA12.Signal=USB_OTG_FS_DP
PA15.Signal=SPI3_NSS
PB3.Signal=SPI3_SCK
PB5.Signal=SPI3_MOSI
PH0-OSC_IN.Signal=RCC_OSC_IN
PH1-OSC_OUT.Signal=RCC_OSC_OUT

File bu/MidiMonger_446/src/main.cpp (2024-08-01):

#include "initialisation.h"
#include "USB.h"
#include "MidiHandler.h"
#include "DACHandler.h"
#include "Config.h"
#include "CDCHandler.h"

volatile uint32_t SysTickVal;

bool CmdPending = false;
std::string ComCmd;

USB usb;
MidiHandler midiHandler;
DACHandler dacHandler;
Config cfg;

uint32_t debugClock = 0;
uint32_t debugClDiff = 0;
bool USBDebug;


extern "C" {
#include "interrupts.h"
}

// As this is called from an interrupt assign the command to a variable so it can be handled in the main loop
void CDCHandler(uint8_t* data, uint32_t length) {
	ComCmd = std::string((char*)data, length);
	CmdPending = true;
}


void LilLightShow() {
	for (uint8_t c = 0; c < 8; ++c) {
		midiHandler.cvOutputs[c > 3 ? 3 - c % 4 : c].ledOn(60);
		uint32_t delay = SysTickVal + 110;
		while (delay > SysTickVal) {
			midiHandler.gateTimer();
		}
	}
}

extern uint32_t SystemCoreClock;
int main(void)
{
	SystemInit();							// Activates floating point coprocessor and resets clock
	InitClocks();					// Configure the clock and PLL
	//SystemCoreClockUpdate();				// Update SystemCoreClock (system clock frequency) derived from settings of oscillators, prescalers and PLL
	InitSysTick();
	dacHandler.initDAC();
	InitMidiUART();
	usb.InitUSB();
	cfg.RestoreConfig();
	midiHandler.setConfig();

	// Bind the usb.dataHandler function to the midiHandler's event handler
	usb.midiDataHandler = std::bind(&MidiHandler::eventHandler, &midiHandler, std::placeholders::_1, std::placeholders::_2);
	usb.cdcDataHandler = std::bind(CDCHandler, std::placeholders::_1, std::placeholders::_2);

	// Little light show
	LilLightShow();



	while (1)
	{

		midiHandler.gateTimer();		// Switches off any pending gates

		// Check for incoming CDC commands
		if (CmdPending) {
			if (!CDCCommand(ComCmd)) {
				usb.SendString("Unrecognised command. Type 'help' for supported commands\n");
			}
			CmdPending = false;
		}

		cfg.SaveConfig();		// Checks if configuration change is pending a save

		// Debug mode - output USB trace via System UART
#if (USB_DEBUG)
		if ((GPIOB->IDR & GPIO_IDR_ID11) == 0 && !USBDebug) {
			USBDebug = true;
			usb.OutputDebug();
		} else {
			USBDebug = false;
		}
#endif
	}
}

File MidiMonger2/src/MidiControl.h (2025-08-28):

#pragma once

#include "initialisation.h"
#include "DACHandler.h"
#include "CDCHandler.h"
#include "configManager.h"
#include <list>


class MidiControl {
	friend class CommandHandler;
public:
	enum MIDIType { Unknown = 0, NoteOn = 0x9, NoteOff = 0x8, PolyPressure = 0xA, ControlChange = 0xB,
		ProgramChange = 0xC, ChannelPressure = 0xD, PitchBend = 0xE, System = 0xF };
	enum class GateType { specificNote = 1, channelNote = 2, clock = 3 };
	enum class CvType { channelPitch = 1, controller = 2, pitchBend = 3, afterTouch = 4 };
	enum class ConfigSetting { type = 1, specificNote = 2, channel = 3, controller = 4 };
	enum class OutputType { gate, cv };
	enum class LightShowType {startup, connection};
	MidiControl();
	void MidiEvent(const uint32_t data);
	void SerialHandler(uint32_t data);
	static void SetConfig();
	void GateTimer();
	void CalcPortamento();
	void LightShow(LightShowType);

	// Commands allowing external classes (eg USB HID) to output data
	void SendCV(uint16_t dacOutput, uint8_t channel, uint32_t ledTimoutMS);
	void SendGate(uint8_t gate, bool on);

	ConfigSaver configSaver = {
		.settingsAddress = &cfg,
		.settingsSize = sizeof(cfg),
		.validateSettings = SetConfig
	};


	union MidiData {
		MidiData(uint32_t d) : data(d) {};
		MidiData()  {};

		uint32_t data;
		struct {
			uint8_t CIN : 4;
			uint8_t cable : 4;
			uint8_t chn : 4;
			uint8_t msg : 4;
			uint8_t db1;
			uint8_t db2;
		};
		// Used primarily for transferring configuration data to the editor
		struct {
			uint8_t Code;
			uint8_t db0;
			uint8_t cfgChannelOrOutput : 4;	// holds channel of config data being transferred.	Byte position: ----dddd
			uint8_t configType : 4;			// holds type of config data being transferred.		Byte position: dddd----
			uint8_t configValue;			// value of note number or controller configured
		};
	};

	static constexpr uint32_t midiDebugSize = 400;
	MidiData debugEvents[midiDebugSize];
	uint32_t midiDebugCount = 0;
	uint32_t midiDebugFilterCount = 0;

private:
	void GatesOff();
	void QueueInc();
	void MatchChannelSetting(OutputType isGate, uint8_t num);

	static constexpr uint8_t chNoteCount = 4;

	struct ChannelNote {
		uint8_t playingNotes[chNoteCount];
		uint8_t voiceCount;
		uint8_t lastVoice;					// for round robin assignment of notes to voices
		float pitchbend;
	};
	ChannelNote channelNotes[16];			// For managing pitch bends and polyphony - stores voice count and active notes for each channel

	struct Gate {
		GateType type;
		uint8_t channel;
		uint8_t note;
		GpioPin output;
		uint32_t gateOffTime;
		Gate(GateType type, uint8_t channel, uint8_t note, GPIO_TypeDef* gpioPort, uint8_t gpioPin) :
			type(type), channel(channel), note(note), output(gpioPort, gpioPin, GpioPin::Type::Output) {};

		void GateOn(const uint32_t offTime) {					// Gate on also setting off time for use with clocks
			output.SetHigh();
			gateOffTime = offTime;
		}
	};

#ifdef V1_HARDWARE
	Gate gateOutputs[8] = {
			{GateType::channelNote,  1, 0,   GPIOA, 7},
			{GateType::channelNote,  2, 0,   GPIOA, 3},
			{GateType::channelNote,  3, 0,   GPIOA, 5},
			{GateType::channelNote,  4, 0,   GPIOC, 5},
			{GateType::specificNote, 10, 36, GPIOC, 1},
			{GateType::specificNote, 10, 38, GPIOB, 2},
			{GateType::specificNote, 10, 42, GPIOC, 9},
			{GateType::specificNote, 10, 46, GPIOC, 7}
	};
#else
	Gate gateOutputs[8] = {
			{GateType::channelNote,  1, 0,   GPIOB, 0},
			{GateType::channelNote,  2, 0,   GPIOC, 4},
			{GateType::channelNote,  3, 0,   GPIOB, 2},
			{GateType::channelNote,  4, 0,   GPIOA, 7},
			{GateType::specificNote, 10, 36, GPIOB, 12},
			{GateType::specificNote, 10, 38, GPIOA, 5},
			{GateType::specificNote, 10, 42, GPIOB, 14},
			{GateType::specificNote, 10, 46, GPIOC, 3}
	};
#endif

	struct CV {
		CvType type;
		uint8_t channel;
		DACHandler::Address dacChannel;
		GpioPin led;
		uint32_t offTime;
		uint8_t controller;
		uint8_t currentNote;
		uint8_t prevNote;
		uint8_t nextNote;

		// Portamento settings
		bool portamento;
		float currentOutput;
		float targetOutput;

		CV(CvType type,	uint8_t channel, DACHandler::Address dacChannel, GPIO_TypeDef* gpioPort, uint8_t gpioPin) :
			type(type), channel(channel), dacChannel(dacChannel), led(gpioPort, gpioPin, GpioPin::Type::Output) {};
		void SendNote();
		void LedOn(float offMs) {
			led.SetHigh();
			offTime = SysTickVal + (offMs * 2.5);				// pass gate off time: each tick is around 400us: 2500 x 400us = 1 second
		}
	} cvOutputs[4] = {
			{CvType::channelPitch, 1, DACHandler::ChannelD, GPIOC, 14},
			{CvType::channelPitch, 2, DACHandler::ChannelC, GPIOC, 13},
			{CvType::channelPitch, 3, DACHandler::ChannelB, GPIOB, 8},
			{CvType::channelPitch, 4, DACHandler::ChannelA, GPIOB, 7}
	};

	static constexpr float dacOffsetDefault = 25.3f;
	static constexpr float dacScaleDefault = 74.0f;
	static constexpr float pitchBendSemiTonesDefault = 12.0f;						// Number of semitones for a full pitchbend
	struct Config {
		struct GateConfig {
			GateType type;
			uint8_t channel;
			uint8_t note;
		} gates[8];

		struct CVConfig {
			CvType type;
			uint8_t channel;
			uint8_t controller;
		} cvs[4];

		float pitchBendSemiTones = pitchBendSemiTonesDefault;						// Number of semitones for a full pitchbend
		uint8_t portamento = 0;

		float dacOffset = dacOffsetDefault;
		float dacScale = dacScaleDefault;
	} cfg;


	float dacScaleCalc;							// dac scaling adjusted for 16 bit output
	float portamentoCalc;						// Calculated speed of portamento effect

	static constexpr uint32_t QueueSize = 50;
	uint32_t ClockCount = 0;

	uint8_t queue[QueueSize];			// hold incoming serial MIDI bytes
	uint8_t queueRead = 0;
	uint8_t queueWrite = 0;
	uint8_t queueCount = 0;
};

extern MidiControl midiControl;


/*	Configure gates to default values for GM drum sounds
36 Bass Drum 1
37 Rim Shot (Side Stick)
38 Acoustic Snare
39 Hand Clap
40 Electric Snare
41 Low Tom A
42 Closed Hi-Hat
43 Low Tom B
44 Pedal Hi-Hat
45 Mid Tom A
46 Open Hi-Hat
47 Mid Tom B
48 High Tom A
49 Crash Cymbal
*/

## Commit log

2019-10-24 Added handling for monophonic pitch and on/off handling via std::list
2019-10-28 Updates to web editor; added midi handler class
    [MidiMonger.sch]
2019-11-04 Updates to configuration message exchange; schematic revised to include gate output
2019-11-05 Editor can now configure CV outputs; fixed USB/MIDIHandler binding
    [MidiMonger.sch]
2019-11-07 Switched to MAX5134 DAC; added test for MIDI channel in editor; NB issue in editor intermittently not receiving config from USB
    [DACHandler.cpp, MidiHandler.cpp, initialisation.cpp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]
2019-11-08 Fixed bug relating to editor crashes; started implementing polyphonic mode
    [MidiHandler.cpp]
2019-11-09 Updated schematic
    [MidiMonger.sch]
2019-11-15 Updated footprints and added LEDs and additional outputs; added handling for serial MIDI
    [MidiMonger.sch]
2019-11-15 Split schematic into control board and electronics board
    [MidiMonger.sch, MidiMonger_controls.sch]
2019-11-16 First draft of control PCB
    [MidiMonger.sch, MidiMonger_controls.kicad_pcb, MidiMonger_controls.sch]
2019-11-18 Rough drafts of controls and electronics PCBs
    [MidiMonger.sch]
2019-11-19 First completed draft of PCB electronic layout
    [MidiMonger.kicad_pcb, MidiMonger_controls.kicad_pcb, MidiMonger_controls.sch]
2019-11-19 Updated silkscreen
    [MidiMonger.kicad_pcb]
2019-11-20 Updated silkscreens and further PCB optimisations
    [MidiMonger.kicad_pcb, MidiMonger.sch, MidiMonger_controls.sch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]
2019-11-22 Panel first draft with components
    [MidiMonger_controls.kicad_pcb]
2019-11-26 First draft of PCBs completed and sent to JLC
    [MidiMonger-B_Cu.gbr, MidiMonger-B_Mask.gbr, MidiMonger-B_Paste.gbr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]
2019-12-02 Fixes to polyphonic notes asignment and reorganised editor to reflect hardware layout
    [MidiHandler.cpp]
2019-12-05 Polyphony fixes and clock improvements
    [MidiHandler.cpp, main.cpp]
2019-12-18 Created separate project for dev board using CodeIDE
2019-12-21 Added startup lightshow; minor bug fixes
    [main.cpp]
2020-07-10 Removed old code and tidied up project
    [MidiMonger_controls.sch]
2020-07-10 Fixed grounding error with output jacks on controls board
    [MidiMonger_controls.kicad_pcb, MidiMonger_controls.sch]
2020-08-01 Switched MIDI endpoints to BULK
2020-08-06 Made 3D model of 5 pin DIN
    [MidiMonger_controls.kicad_pcb]
2020-08-08 Merged combined CDC and MIDI USB functionality and simple test
    [MidiMonger.kicad_pcb]
2020-08-09 Added test code to play notes via COM Port; added image of PCB
2020-08-09 Added PCB images
    [MidiMonger.kicad_pcb]
2020-08-09 Added PDF Schematics
    [MidiMonger.sch, MidiMonger_controls.sch]
2020-08-09 Fixed issue in web editor with channel = 16; added config command to COM interface
    [MidiHandler.cpp, main.cpp]
2020-08-17 Work on FIFO sizes - appears to now be working correctly with large packets
    [MidiHandler.cpp, USB.cpp, USB.h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]
2021-08-22 Clean up schematics
    [MidiMonger_controls.kicad_pcb]
2022-02-06 Reinstated accidentally deleted interrupt.h
2022-03-14 Updated to Kicad v6
2022-03-31 Updates to Kicad 6
2022-10-07 Kicad updates
    [MidiMonger.kicad_sch]
2023-02-28 Added Quad Controls PCB
    [QMidiMonger_controls.kicad_pcb, QMidiMonger_controls.kicad_sch, QMidiMonger_controls.sch]
2023-02-28 Added panel PCB; added board interconnects
    [QMidiMonger_controls.kicad_pcb, QMidiMonger_panel.kicad_pcb, QMidiMonger_panel.step]
2023-03-01 Added inter-board connector
    [QMidiMonger_controls.kicad_pcb, QMidiMonger_controls.kicad_sch, QMidiMonger_panel.kicad_pcb]
2023-03-02 Cleaned up Panel and Controls
    [QMidiMonger_controls-B_Cu.gbr, QMidiMonger_controls-B_Mask.gbr, QMidiMonger_controls-B_Paste.gbr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]
2023-03-02 Fixes to controls board
    [QMidiMonger_controls-B_Cu.gbr, QMidiMonger_controls-B_Mask.gbr, QMidiMonger_controls-B_Paste.gbr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]
2023-03-03 Normalised audio to all CV returns
    [QMidiMonger_controls-B_Cu.gbr, QMidiMonger_controls-B_Mask.gbr, QMidiMonger_controls-B_Paste.gbr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]
2023-03-31 Updated Midi handling to prevent 'voice-stolen' notes replaying once voices available again
    [MidiHandler.cpp]
2024-08-01 Cleaning up usb device code
2024-08-01 Added option to enable/disable USB device
2024-08-01 Started v2 hardware design
    [MidiMonger-B_Cu.gbr, MidiMonger-B_Mask.gbr, MidiMonger-B_Paste.gbr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]
2024-08-02 Updates to PCB layout
    [MidiMonger_components.kicad_pcb, MidiMonger_components.kicad_sch]
2024-08-03 Component PCB first pass routing
    [MidiMonger_components.kicad_pcb]
2024-08-03 Started Control layout
    [MidiMonger_components.kicad_pcb, MidiMonger_components.kicad_sch, MidiMonger_controls.kicad_pcb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]
2024-08-06 Laying out panel
    [MidiMonger_components.kicad_pcb, MidiMonger_components.kicad_sch, MidiMonger_controls.kicad_pcb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]
2024-08-07 Hardware layout
    [MidiMonger_components.kicad_pcb, MidiMonger_components.kicad_sch, MidiMonger_controls.kicad_pcb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]
2024-08-08 Gerbers prepared for manufacture
    [MidiMonger_components-B_Cu.gbr, MidiMonger_components-B_Mask.gbr, MidiMonger_components-B_Paste.gbr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]
2024-08-09 Added additional decoupling capacitors to 5V line
    [MidiMonger_components-B_Cu.gbr, MidiMonger_components-B_Mask.gbr, MidiMonger_components-B_Paste.gbr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]
2024-08-21 Fixes to mode switching; added serial MIDI support
    [USB.cpp, initialisation.cpp, main.cpp]
2024-08-22 Fixing issues with CV type changing and pitchbend
    Clean up project
    [DACHandler.cpp, MidiHandler.cpp, USB.cpp]
2024-08-23 Fixed issues managing config
    [DACHandler.cpp, initialisation.cpp]
2024-08-25 Fixed v1 conflict with gate 8 and mode switch
    [initialisation.cpp]
2024-09-05 Started adding support for HID class
    Fixed bug in USB host Process state machine in set wakeup feature
    [USBHost.cpp, USBHost.h, uartHandler.cpp]
2024-09-11 Command UI can be accessed over both USB serial and UART
2024-09-13 Adding configurable mouse controls
    Altered config handler to resolve global initialisation order issues
    Increased priority of UART interrupts to avoid USB interrupt blocking
    [CommandHandler.cpp, HidDescriptor.h, initialisation.cpp]
2024-09-17 Added schematics
2025-03-07 Reversed MIDI device/host graphics on panel v2.1
    [MidiMonger_panel.kicad_pcb]
2025-03-09 Fix to usb device under Linux
    EP0In not respecting request length
    [CommandHandler.cpp, USB.cpp, USB.h]
2025-08-18 Fixes to round-robin assignment; Reset USB core to improve switching from host to device mode
    [CommandHandler.cpp, MidiControl.h, USB.cpp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]
2025-08-19 Reduced clock to 120MHz; fixed pitch bend on released notes
    +12V rail current reduced from 124mV to 102mV
    [MidiControl.h, MidiMonger2.ioc, initialisation.cpp]
2025-08-24 Handle NoteOn event with velocity = 0 meaning NoteOff
2025-08-26 Fixed issue processes USB Misc classes
    [USBHost.cpp]
2025-08-27 Test code for processing problem config descriptors
    [CommandHandler.cpp, USBHost.cpp]
2025-08-28 Rewrote note allocation code to avoid using std::list
    [MidiControl.h]
2025-09-27 Fixes to pitchbend test and led
    [USBHost.cpp]
2025-12-11 Fix skipped notes by correcting channelNotes indexing and handling multi-event USB MIDI packets
    [MidiHandler.cpp]
